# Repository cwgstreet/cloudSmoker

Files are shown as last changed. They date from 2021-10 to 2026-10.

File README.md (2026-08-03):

<div align="right">
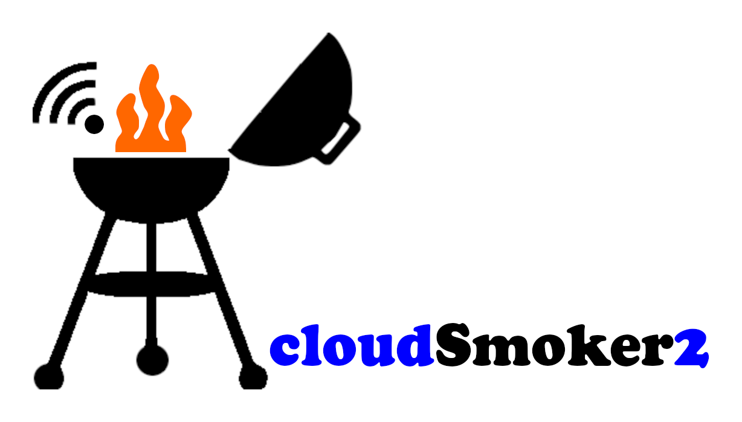
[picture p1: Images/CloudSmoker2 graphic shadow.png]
CloudSmoker2 Graphic
  
</div>
<br>

---

#  cloudSmoker2

# :construction: **Under Development**

⚠️ **Version 2 Notice:** 
<br>

**This is the active development 
branch for cloudSmoker V2. The original design is now deprecated but remains available on the v1-legacy branch.**

___





# Project Summary

The **cloudSmoker** is a WiFi-enabled barbeque temperature monitor designed to take the guesswork out of low-and-slow cooks. 

Building on the reliable foundation of the original cloudSmoker1 2022 release, Version 2 modernises the platform with a focus on precision, expanded capabilities, and a more comprehensive hardware design.

### What’s New in cloudSmoker2
*   **Expanded Monitoring:** Now supports up to four temperature probes for lager cooks.
*   **Enhanced Precision:** Improved measurement accuracy and response via higher-resolution ADC, optimised bias resistor selection plus improved filtering and ADC management.
*   **Modern Hardware:** Upgraded to a contemporary microcontroller, a refreshed display, and a custom 3D-printed enclosure.
*   **Professional Build:** Transitioning to a custom-manufactured PCB using contemporary SMD (Surface Mount) components for increased reliability and a more compact footprint.
*   **Refined Software:** Features seamless OTA (Over-The-Air) firmware updates, streamlined configuration menus, and robust exception monitoring.

### How it Works
The device tracks critical data points, such as pit and internal meat temperatures, and syncs them to an IoT dashboard. This allows for remote monitoring of real-time graphs and gauges from any browser or smartphone. 

To ensure the cook stays on track, the system sends push notifications if temperatures drift or once the meat reaches its target. The project is designed to be cooker-agnostic, making it a reliable companion for a variety of smokers and BBQ setups.

> ### 🌟 **Update:** cloudSmoker2 development is progressing!
>
1) **Boards now built and firmware port / enhancement is underway.**

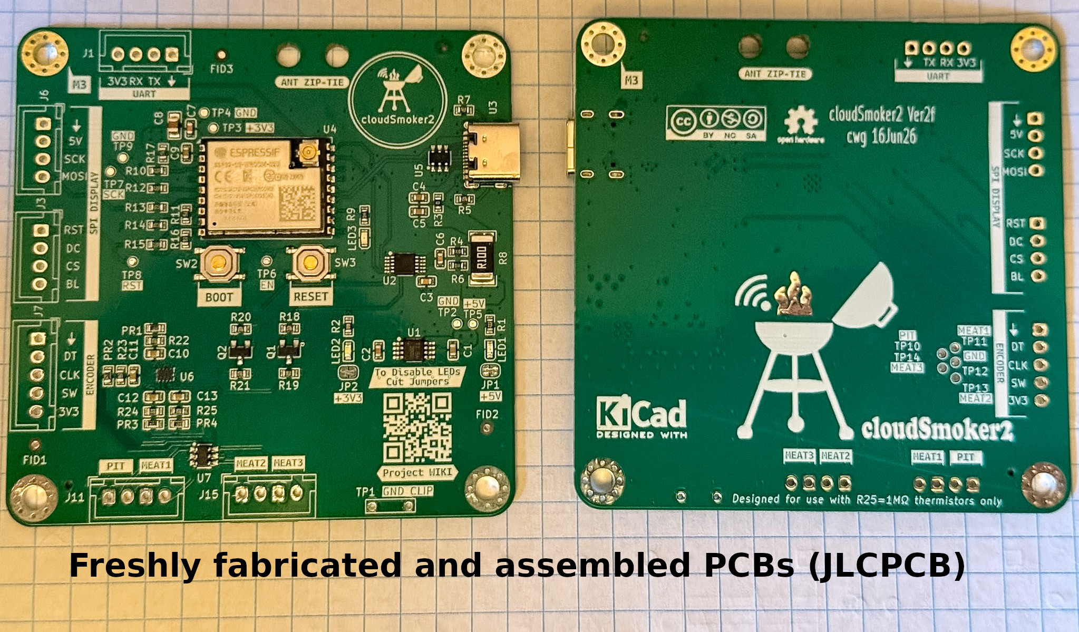
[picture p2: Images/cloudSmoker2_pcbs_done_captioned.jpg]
 

<br clear="left"/>
<br>

2) **3D printed enclosure design well advanced**
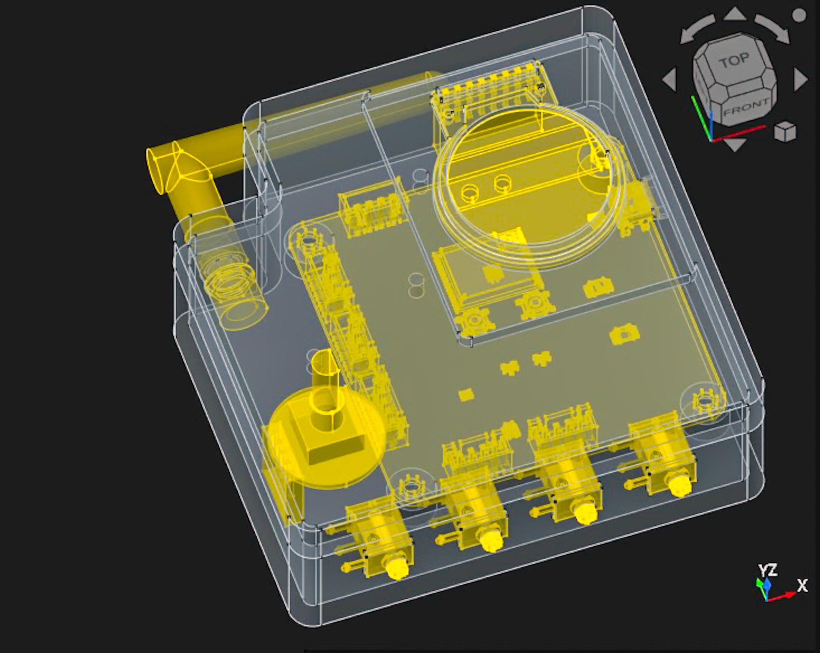
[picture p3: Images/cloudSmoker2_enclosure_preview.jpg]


<br clear="left"/>
<br>

<br>
<br>
<br>
<br>

---

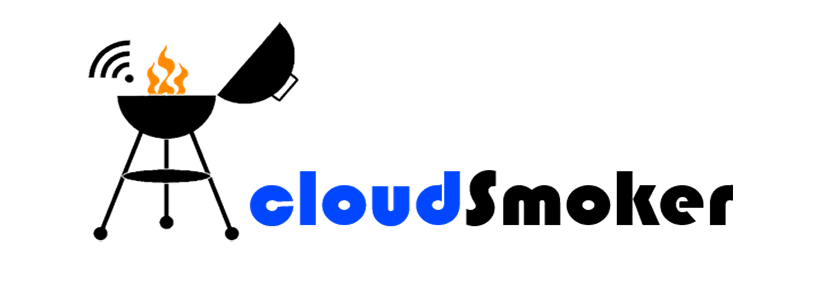
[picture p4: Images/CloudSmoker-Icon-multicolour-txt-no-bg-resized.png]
 
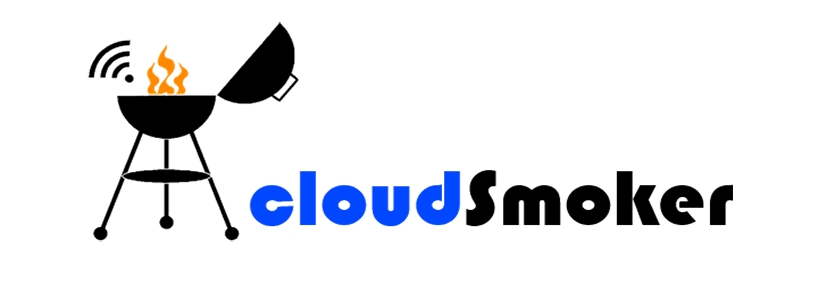
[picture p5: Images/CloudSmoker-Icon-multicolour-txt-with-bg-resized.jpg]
  

<br>

<br>

# cloudSmoker (v1-legacy) #

## 📜 Legacy Support (Version 1.0)
The original version of this project was based on an **ESP8266** and was built on **Veroboard**. While it is no longer the main focus of development, you can still access all the original files:

*   **[Version 1.0 Release Page](https://github.com/cwgstreet/cloudSmoker/releases/tag/v1.0)**
    *   `Hardware_v1.0.zip`: Includes Fritzing layouts, PDF schematics, and build photos.
    *   `Firmware_v1.0.zip`: The stable code and compiled `.bin` for the original build.

<!-- >**Note:** If you are building this project for the first time, we recommend using the **Version 2** PCB files found in this main branch. -->

**WiFi BBQ Temperature Monitor Project**

[comment]: <> (This project exists as a hands-on opportunity to learn more about electronics, IoT, Arduino / ESP8266 programming, GitHub markdown, etc)


<a href="https://thingspeak.com/channels/1679986">
    </a> 

 

<br>

<p align="center">
  <a href="https://hackaday.com/2022/08/09/smoking-meat-finds-natural-home-in-the-cloud/">
    
  </a>
</p>

### Updates (ver1)
1. **Removed pitTemp probe plug-in checks** - no longer displays LCD error or transmits pitTemp values to ThingSpeak if pit temperature probe is unplugged; necessary to allow pitTemp probe to be unplugged after meat is taken off grill so that resting meat temps can continue to be monitored (common to rest briskett in faux cambo for ~1 hour after removing meat from grill).
<br>
<br>

## Project Summary

The cloudSmoker Barbecue Monitor project is a WiFi-enable temperature monitor.  cloudSmoker is designed to read two temperatures (pit and internal meat temperatures) within my Weber BBQ smoker and upload these to an IOT dashboard, allowing remote cloud monitoring of the cook progress showing temperature vs time graphs, gauges, etc, user-definable cooking notification setpoints and exception push notifications to my smartphone, say if the pit temperatures go outside of acceptable ranges and when the meat is done and ready to be removed.

The overall process flow is conceptualised as follows:

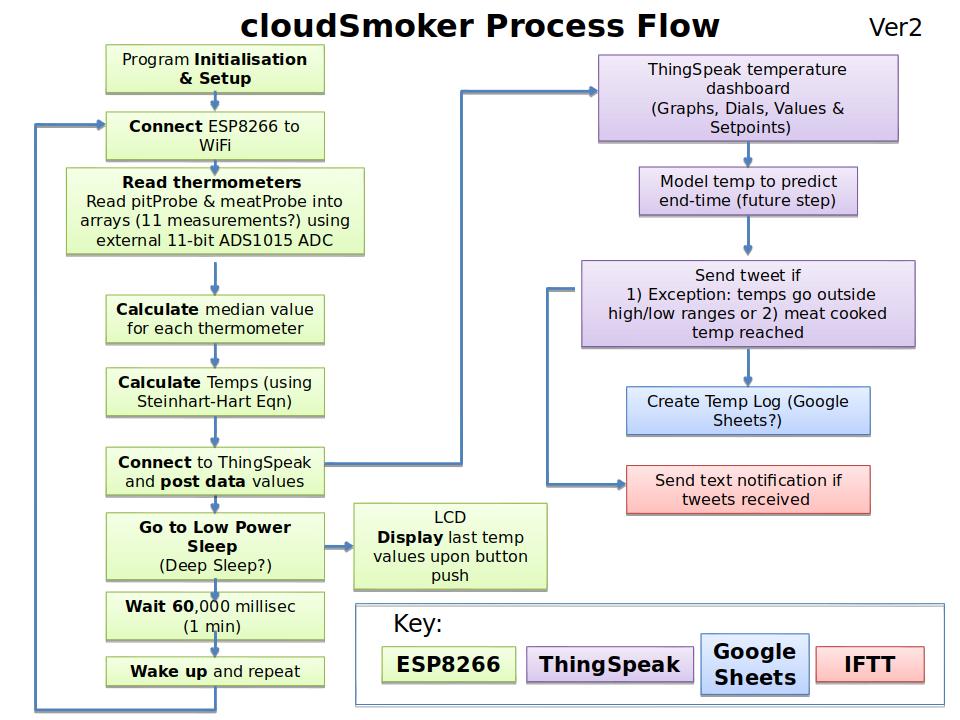
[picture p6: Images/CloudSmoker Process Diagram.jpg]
 

Hardware is based around the NodeMCU (V1.0) ESP8266-12E microcontroller module (for both for WiFi access and microcontroller), two Maverick ET-732/733 thermistor probes, an external ADS1015 "12-bit" ADC, plus a 1602 LCD and rotary encoder for user set-up configuration and display.  Minor thermistor and power filtering was also employed for stability.  

Coding was done using VS Code / PlatformIO IDE platform with data uploaded to ThingSpeak for display and further processing.   Push exception notifications are done through Twitter using Thingspeak's React / ThingTweet functionality.  (:warning: Todo:  export cook logs to Google Sheets).

### Project Overview  ###

An extensive project overview and design process description can be found in the project [Wiki](https://github.com/cwgstreet/cloudSmoker/wiki) covering design goals, hardware, software, etc.  

### Hardware ###

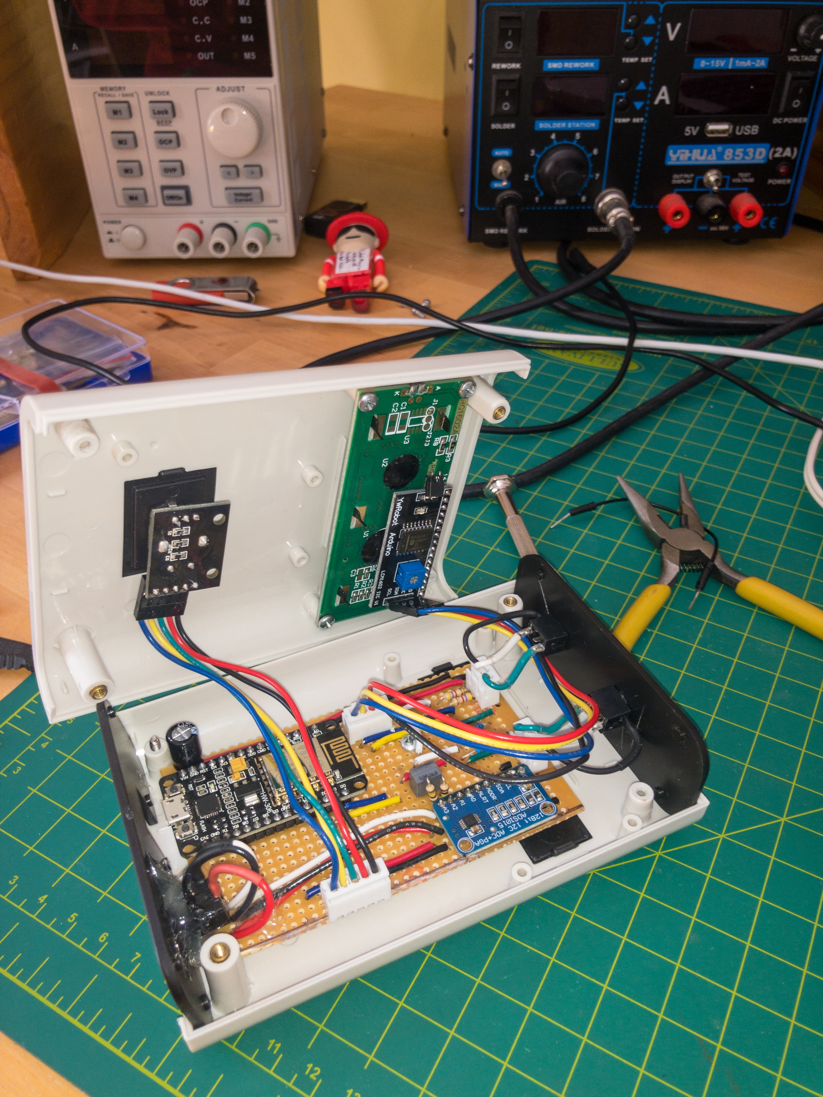
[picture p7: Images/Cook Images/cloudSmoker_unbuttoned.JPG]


The Hardware folder contains KiCad schematic, PCB board layouts (:warning: TODO) and selected datasheets (including the datasheet for the Semitec 105GT-2 Thermistor, that Maverick customer support kindly provided me.   👏 👍

Note that I have not found this datasheet available anywhere on the web and many other projects incorrectly characterised the Maverick ET-732/733 probes as being based on a 10k ohm thermistor (when it's actually 1M ohm!).  This incorrect assumption frequebtly led to poor bias resistor selection, resulting in poor measurement acuracy.  As a result, these Maverick thermistors were often not highly regrded.  For example, one project concluded they were [acceptable, but not recommended thermistor choice](https://github.com/CapnBry/HeaterMeter/wiki/HeaterMeter-Probes).   

### cloudSmoker ###

This folder contains the full cloudSmoker software (sketch and libraries); developed under VSCode / Platformio IDE rather than Arduino IDE so folder structure reflect Platformio structure.  Note that the project code base is over 1600 lines total and makes extensive use of user and public libraries.

### Images ###

Self-explanatory

### Project Dashboard ###
A public ThingSpeak [cloudSmoker dashboard](https://thingspeak.com/channels/1679986) is available

<p align="center">
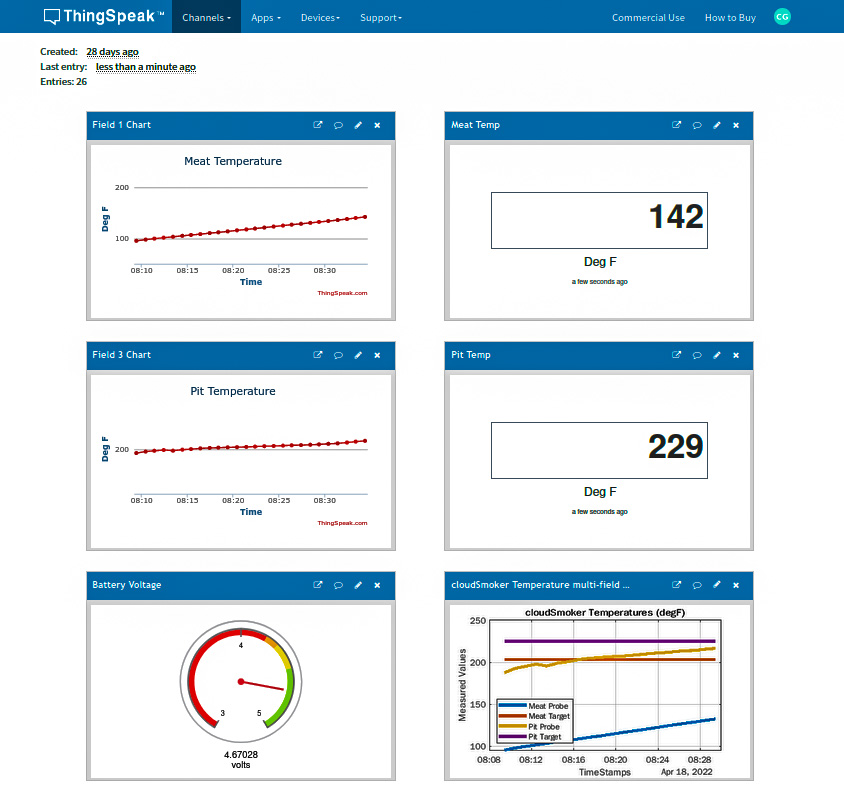
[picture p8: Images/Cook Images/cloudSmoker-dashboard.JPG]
  
</p>

### Licence ###

**cloudSmoker (ver1):** MIT Licence.  Note that licence terms have changed for cloudSmoker2 (Ver2)

--- END ---

<p align="center">
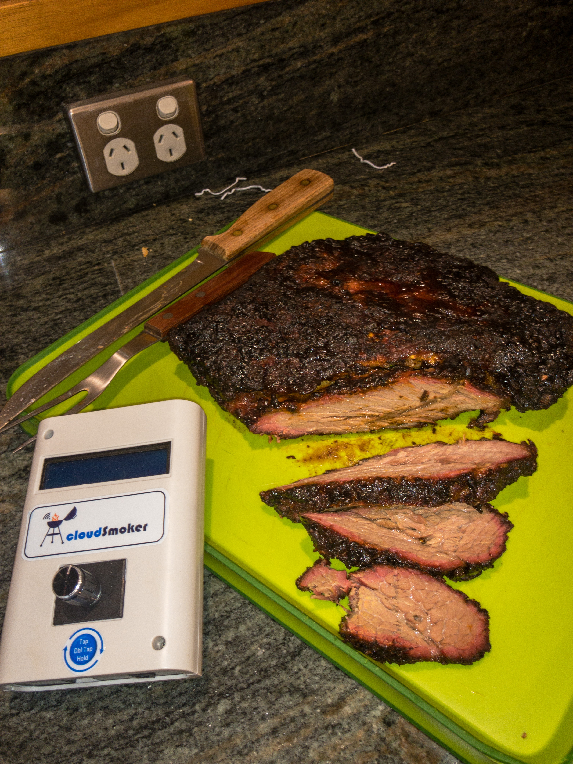
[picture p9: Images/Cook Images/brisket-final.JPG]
  
</p>

<br>
<br>

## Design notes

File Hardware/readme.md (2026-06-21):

# cloudSmoker2 Hardware Reference

This directory serves as the root hardware repository for the **cloudSmoker2** platform. It contains mechanical housing documents, sensor calibration resources, manufacturing documentation, and the complete electronic design suite.

---

## 📂 Repository Structure

```text
├── KiCad9/                          # Core ECAD design environment (KiCad 9.x)
│   ├── cloudSmoker_ver2f.kicad_pro  # Main project configuration
│   ├── cloudSmoker_ver2f.kicad_sch  # 4-Layer Schematic blueprints
│   ├── cloudSmoker_ver2f.kicad_pcb  # Mixed-signal PCB layout 
│   ├── sym-lib-table & fp-lib-table # Local dependency resolution tables
│   ├── JLCImport.pretty/            # Component footprints (.kicad_mod)
│   ├── JLCImport.3dshapes/          # 3D structural clearance models (.step / .wrl)
│   ├── production/                  # Manufacturing artifacts (Gerbers, BOM, CPL)
│   └── svg_files/                   # Dynamic high-resolution hardware dashboard graphics
│
├── Thermistor datasheet/            # High-temperature physical probe reference material
│   ├── ET-732 (Thermistor) datasheet scan.pdf
│   └── Maverick ET-732 - 733 (Semitec 105GT-2 Thermistor) datasheet.pdf
│
├── arduino_housing_01_160717_CAD.PDF.pdf   # Mechanical chassis reference dimensions (cloudSmoker1)
└── licence.md                               # Open-source hardware licensing framework
```

## ⚙️ Key File Subsystems

### 1. Electronic Design Automation (`KiCad9/`)
* **ECAD Engine**: Engineered exclusively inside **KiCad 9**. Backward-compatibility issues can occur if parsed with older software builds.
* **Component Portability**: Component symbols, tracking pads, and 3D packages are completely containerized locally inside the `JLCImport` folders. External global library paths are not required to audit the board.
* **Fabrication Files**: The `KiCad9/production/` subdirectory houses pre-compiled fabrication packages including the zipped Gerber layer arrays, coordinates tables (`positions.csv`), and structural parts listings (`bom.csv`).

### 2. Thermistor Data
* **`Thermistor datasheet/`**: Houses structural lookup sheets for the Semitec 105GT-2 high-temp food probes.

### 3. Physical & Enclosure Overlays
* **`arduino_housing_01_160717_CAD.PDF.pdf`**: Legacy cloudSmoker1 mechanical profile drawing used to verify PCB perimeter cuts, mounting hole positions, and connector face alignments against existing chassis designs.

---

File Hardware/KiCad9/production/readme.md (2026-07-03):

**This directory was created with Kicad9 / Fabrication Toolkit plug-in.**

The fabrication toolkit extracts the files necessary for (JLCPCB)[https://jlcpcb.com/] PCB fabrication and PCBA assembly:
 1) cloudSmoker_ver2_2f.zip -> gerber files
 2) bom.csv -> Bill of Materials including JLCPCB Part Numbers
 3) positions.csv -> component positions file for pick & place

Note:  When ordering, check fab house component positions and orientations carefully as translation errors occur between Kicad9 and JLCPCB despite using JLCPCB / EasyEDA footprints imported with JLC Import plug-in

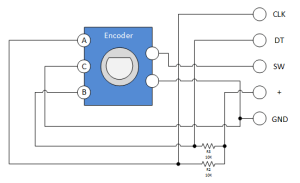
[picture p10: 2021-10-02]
Images/Keyes-KY-040-Rotary-Encoder-Module-Schematic.png

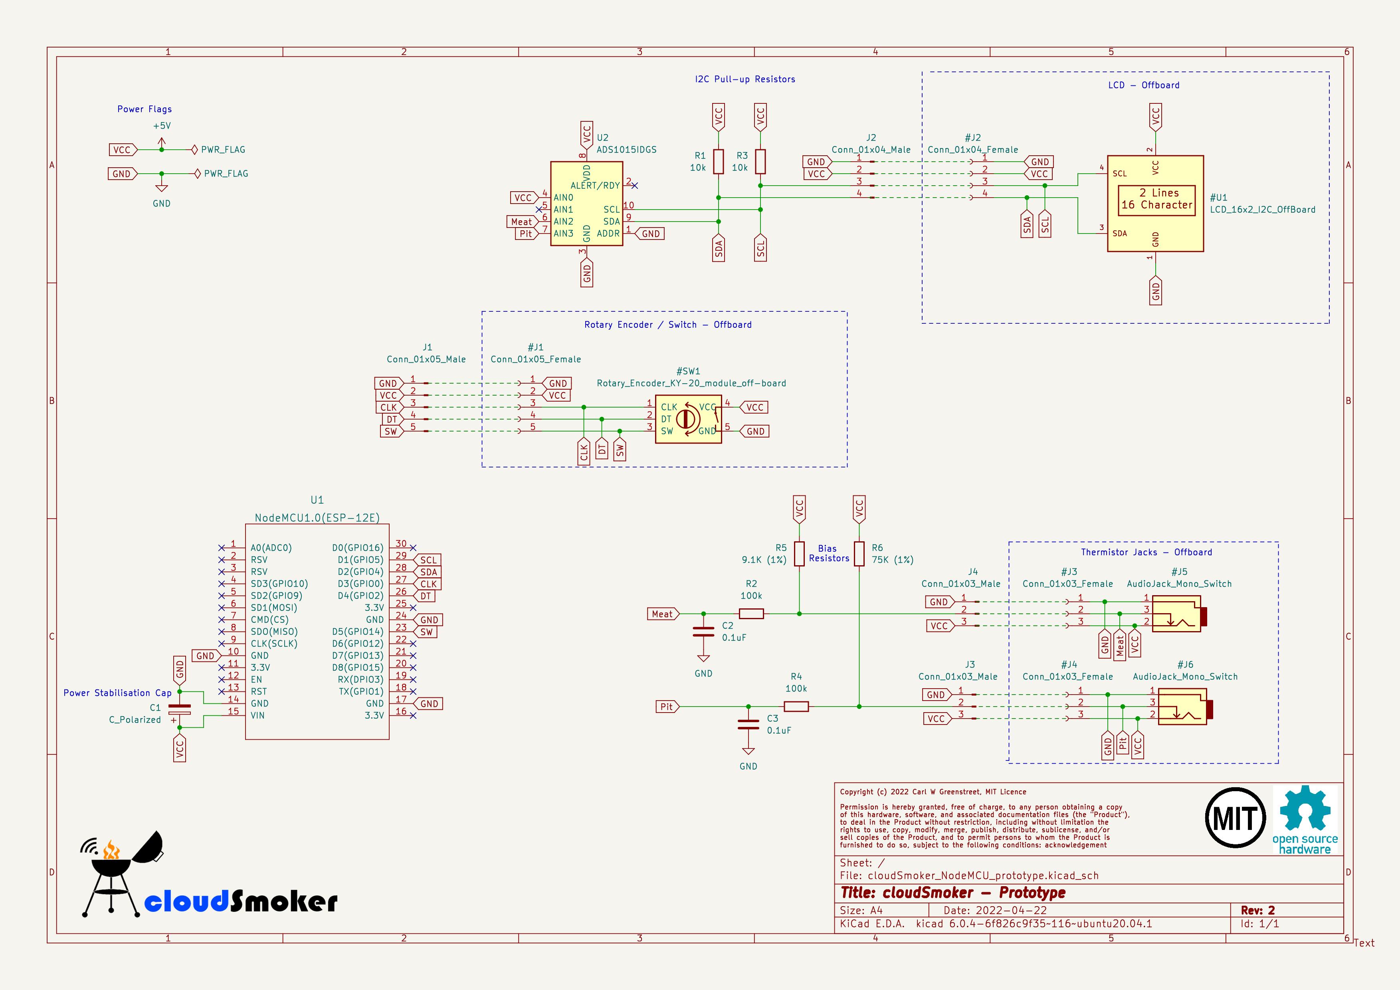
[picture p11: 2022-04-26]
Images/cloudSmoker_prototype_schematic_kicad6.jpg

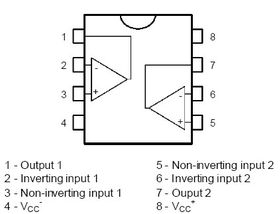
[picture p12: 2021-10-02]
Images/lm358_opamp_pinout.jpg

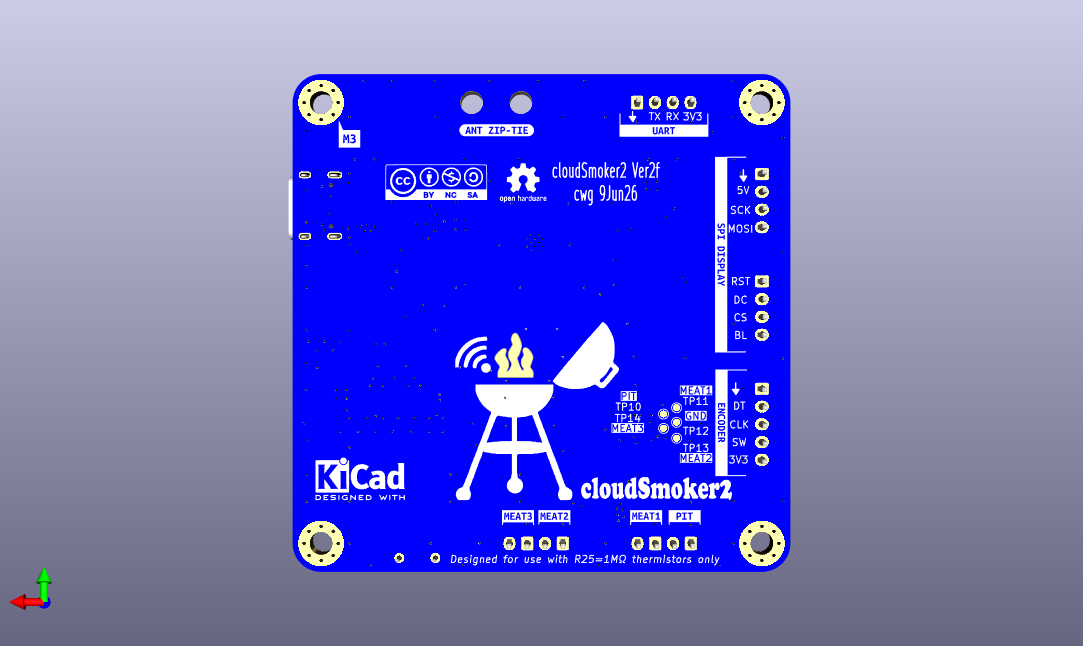
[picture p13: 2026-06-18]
Hardware/KiCad9/svg_files/view3_bottom.png

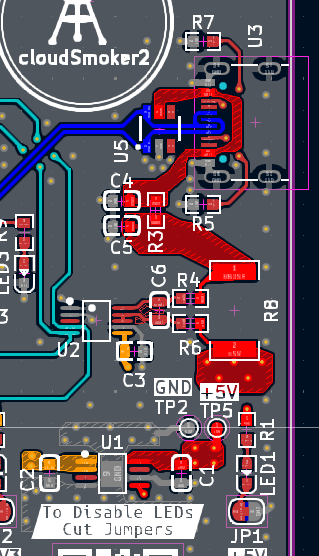
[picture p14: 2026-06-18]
Hardware/KiCad9/svg_files/power_section_closeup.png

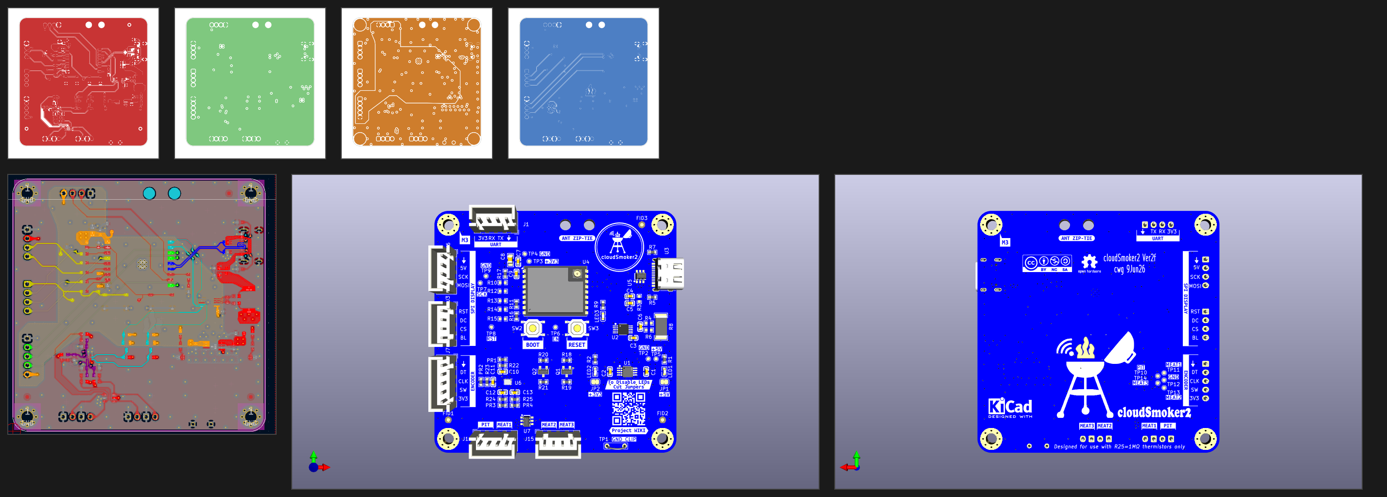
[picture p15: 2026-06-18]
Hardware/KiCad9/svg_files/pcb_dashboard.png

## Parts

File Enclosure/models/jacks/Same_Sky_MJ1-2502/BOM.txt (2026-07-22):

3DX_Same_Sky_Supplier: Same Sky
3DX_Same_Sky_Description: 2.5 mm, Mono, Right Angle, Through Hole, Threaded Bushing, 2 Conductors, 1 Internal Switch, Audio Jack Connector
3DX_Same_Sky_Model Number: MJ1-2502

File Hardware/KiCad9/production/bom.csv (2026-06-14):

Designator | Footprint | Quantity | Value | LCSC Part #
C1, C10, C11, C12, C13, C9 | CL10A105KB8NNNC | 6 | 1uF | C15849
C2 | CL10A225KO8NNNC | 1 | 2.2uF | C23630
C3, C6, C7 | CC0603KRX7R9BB104 | 3 | 100nF | C14663
C4, C5 | CC0603KRX7R9BB104 | 2 | 470nF | C1623
C8 | CL21A106KAYNNNE | 1 | 10uF | C15850
LED1 | KT-0603R | 1 | Red | C2286
LED2 | 0603White_light_C2290 | 1 | White | C2290
LED3 | FC-1608YXK-585F08 | 1 | Yellow | C89811
PR1, PR2, PR3, PR4 | PTFR0603B120KP9 | 4 | 120k 0.1%TF | C351687
Q1, Q2 | BSS138_C7420339 | 2 | BSS138 | C7420339
R1 | 0603WAF2201T5E | 1 | 2.2k | C4190
R10, R12, R13, R14, R15 | R0603_part-C23345 | 5 | 22 | C23345
R11, R16, R17, R19, R21, R22, R23, R24, R25 | 0603WAF1002T5E | 9 | 10k | C25804
R18, R20, R5, R7 | 0603WAF5101T5E | 4 | 5.1k | C23186
R2 | 0603WAF1001T5E | 1 | 1k | C21190
R3 | R0603_part-C21189_0-ohm | 1 | 0 ohm | C21189
R4, R6 | R0603_part-C22859_10-ohm | 2 | 10 | C22859
R8 | RLP25FEER100 | 1 | 100 mOhm Shunt | C160587
R9 | 0603WAF1000T5E | 1 | 100 | C22775
SW2, SW3 | TS-1187A-B-A-B | 2 | SW_Push_Dual | C318884
U1 | TLV76733DGNR | 1 | TLV76733DGNR | C2873382
U2 | INA226AIDGSR | 1 | INA226AIDGSR | C49851
U3 | USB_C_Receptacle_G-Switch_GT-USB-7010ASV clipped | 1 | GT-USB-7010ASV | C2988369
U4 | ESP32-C3-WROOM-02U | 1 | ESP32-C3-WROOM-02U-N4 | C2926676
U5, U7 | SRV05-4-P-T7 | 2 | SRV05-4-P-T7 | C85364
U6 | ADS1115IRUGR | 1 | ADS1115IRUGR | C2651328

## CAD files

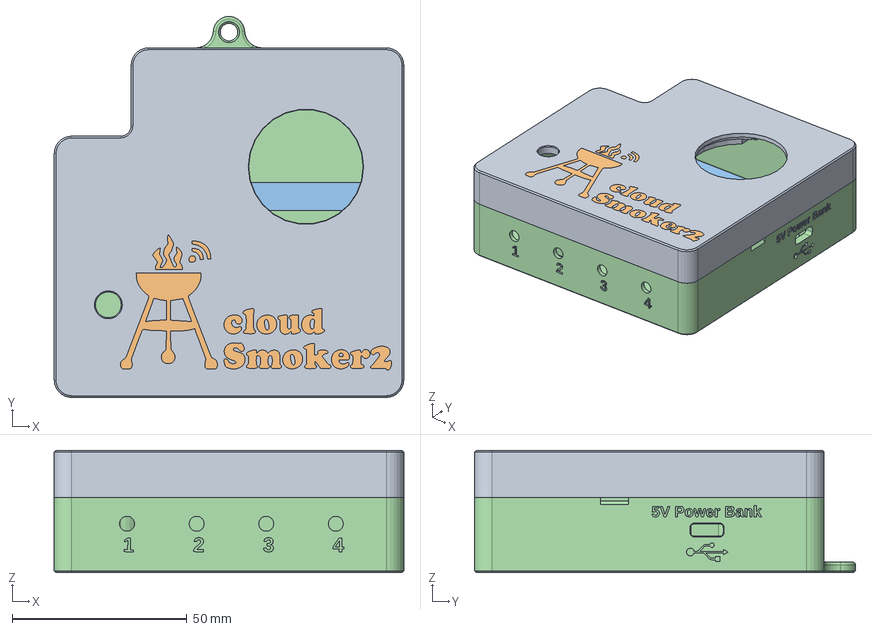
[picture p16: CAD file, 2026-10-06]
Enclosure/cloudSmoker2_enclosure_ver2b.FCStd
100.0 x 109.0 x 35.0 mm
top_enclosure_refined_copy
top_logo_refined_copy
display_clip_refined_copy
base_enclosure_refined_copy

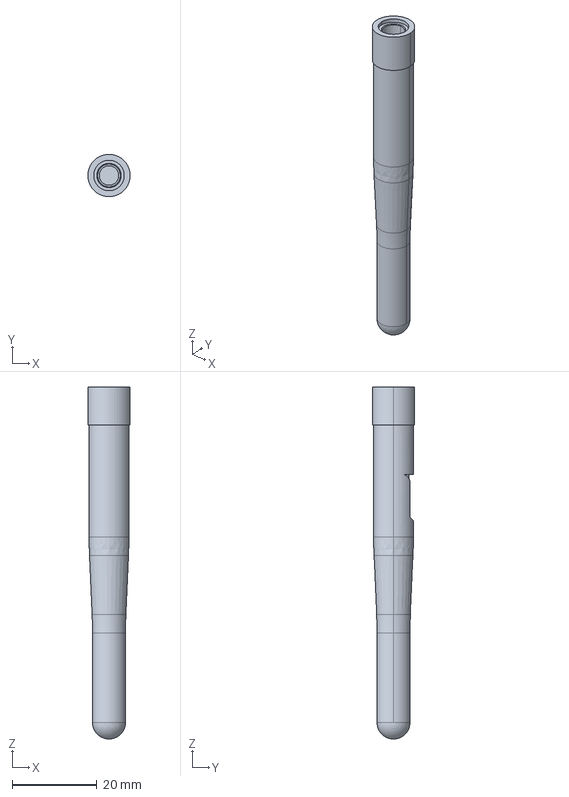
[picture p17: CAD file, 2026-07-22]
Enclosure/models/antenna/ENG_CVM_CVM_L9000081-01_A.3d_stp/c-l9000081-01-a-3d.stp
10.0 x 10.0 x 83.1 mm

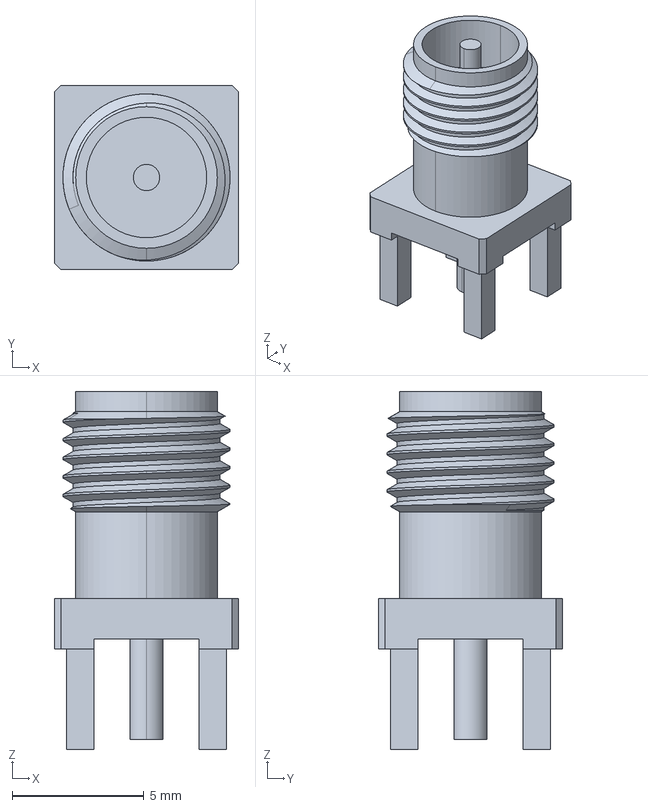
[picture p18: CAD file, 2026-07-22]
Enclosure/models/antenna/RP-SMA_conn/c-conrevsma001-g-c-3d.stp
7.00 x 7.00 x 13.6 mm

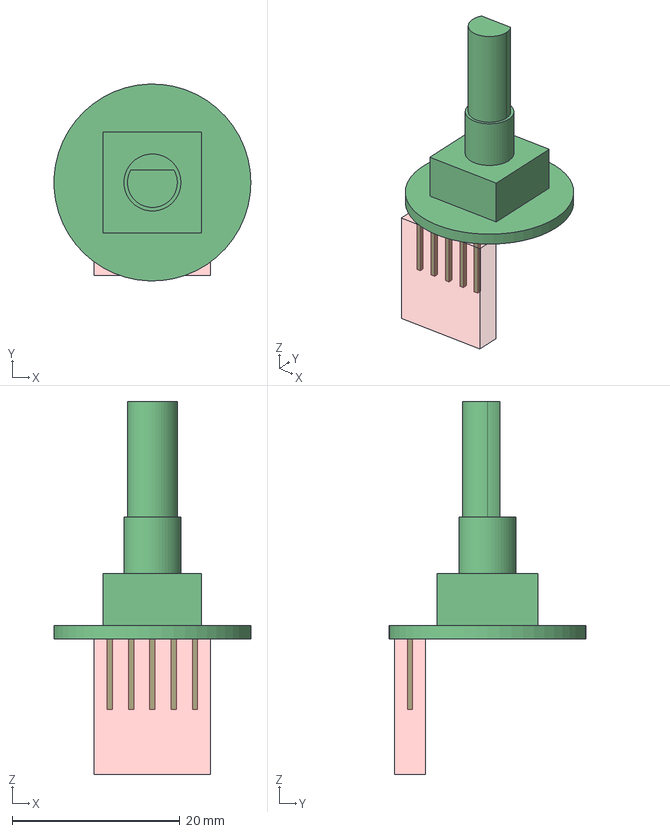
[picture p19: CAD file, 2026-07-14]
Enclosure/models/EC11 rotary encoder/EC11_encoder_module.step
23.5 x 23.5 x 44.5 mm
Encoder_DuPont_Clearance
EC11_Round_Module

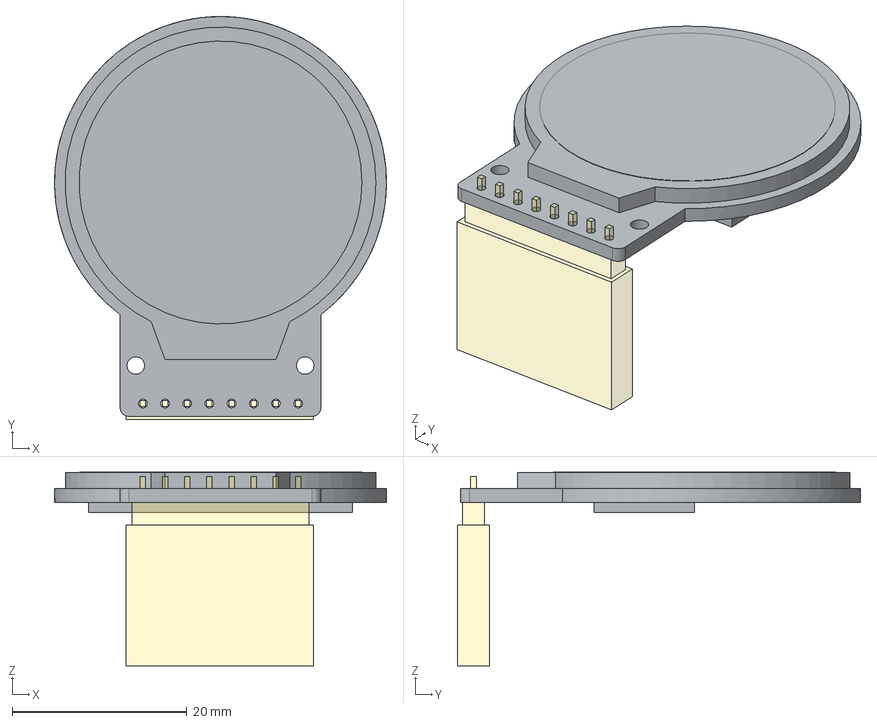
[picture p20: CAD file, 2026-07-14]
Enclosure/models/GC9A01_display/GC9A01_Dsiplay.step
38.0 x 46.2 x 22.2 mm
Male_Header_1x08 Binder
DuPont_1x8_Clearance_Zone Binder

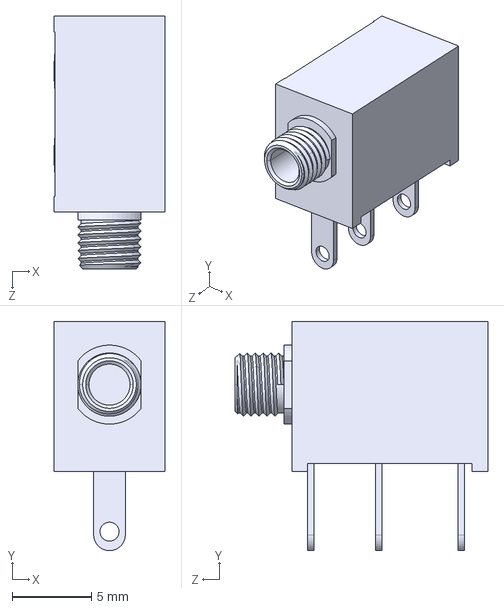
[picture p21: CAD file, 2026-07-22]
Enclosure/models/jacks/Same_Sky_MJ1-2502/Same_Sky_MJ1-2502.step
7.00 x 14.5 x 16.0 mm

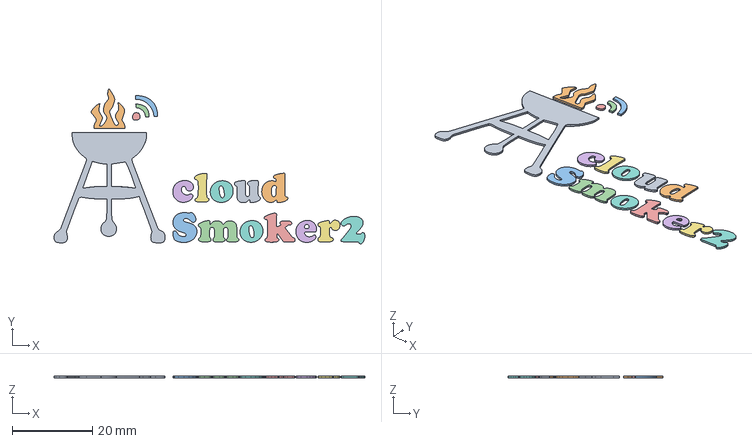
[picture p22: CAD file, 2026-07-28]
Enclosure/models/logo/cloudSmoker_logo.step
77.6 x 38.6 x 0.4 mm

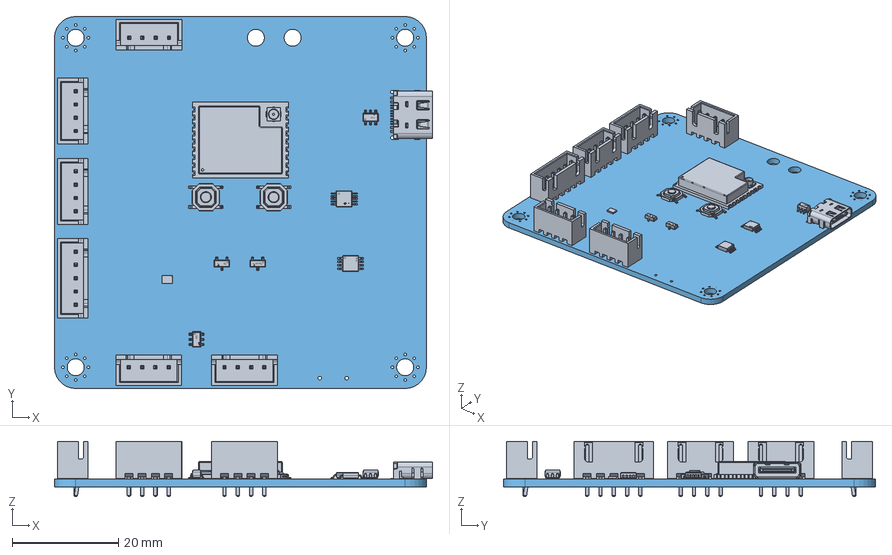
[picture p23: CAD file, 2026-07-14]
Enclosure/models/pcb/cloudSmoker_ver2f.step
71.2 x 70.0 x 10.4 mm
INA226AIDGSR
JST_XH_B4B-XH-A_1x04_P2.50mm_Vertical x 5
TLV76733DGNR
ADS1115IRUGR
BSS138_C7420339 x 2
SRV05-4-P-T7 x 2
ESP32-C3-WROOM-02U
TS-1187A-B-A-B x 2
GT-USB-7010ASV x 3
JST_XH_B5B-XH-A_1x05_P2.50mm_Vertical
cloudSmoker_ver2f_PCB

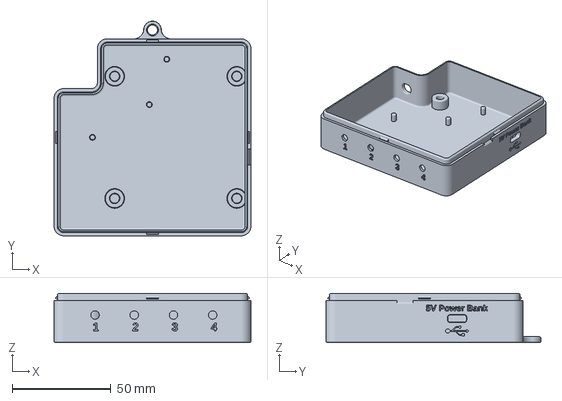
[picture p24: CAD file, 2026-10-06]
Enclosure/print_files/cloudSmoker2_ver2b_base_enclosure_v1.3mf
100.0 x 109.0 x 25.0 mm

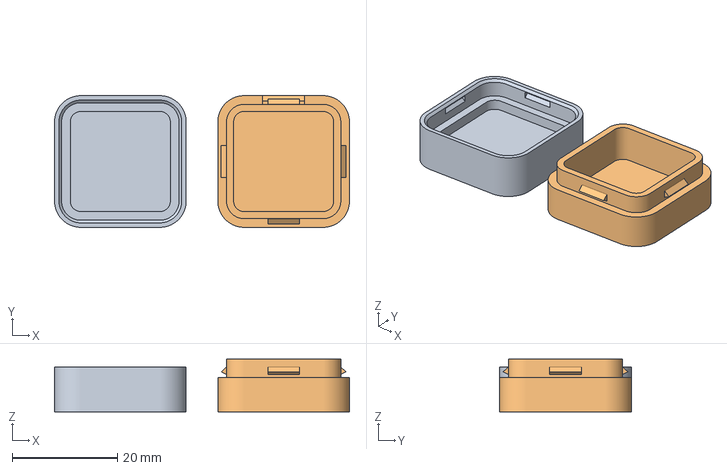
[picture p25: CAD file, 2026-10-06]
Enclosure/print_files/snap-fit_test/snap_fit_test-top-bottom.3mf
56.0 x 25.0 x 10.0 mm
snap_fit_test-top
snap_fit_test-Base

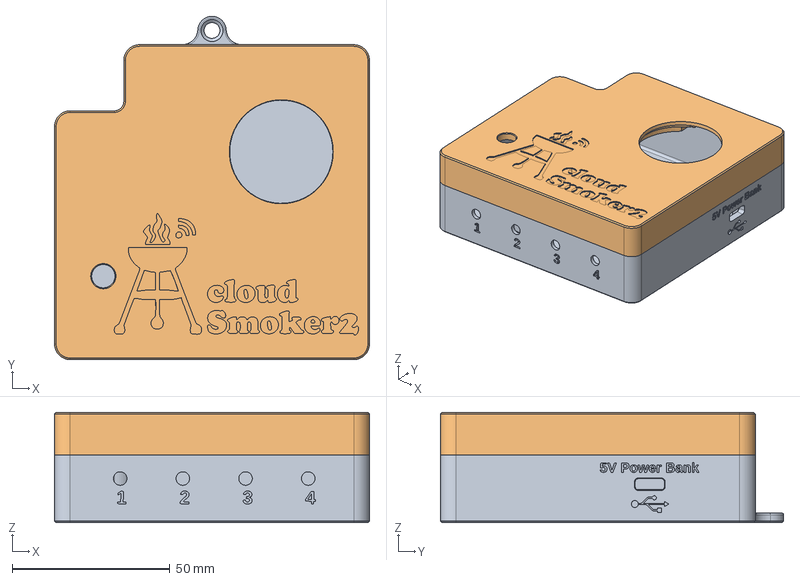
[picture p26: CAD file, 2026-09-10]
Enclosure/cloudSmoker2_enclosure_ver2a.FCStd
100.0 x 109.0 x 35.0 mm
base_enclosure
top_enclosure

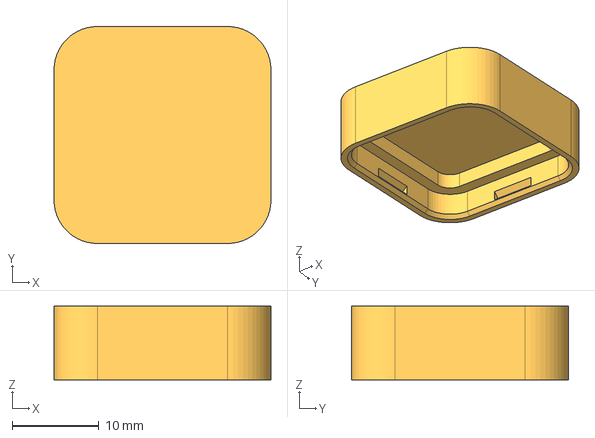
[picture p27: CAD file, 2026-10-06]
Enclosure/print_files/snap-fit_test/snap_fit_test-top.step
25.0 x 25.0 x 8.50 mm

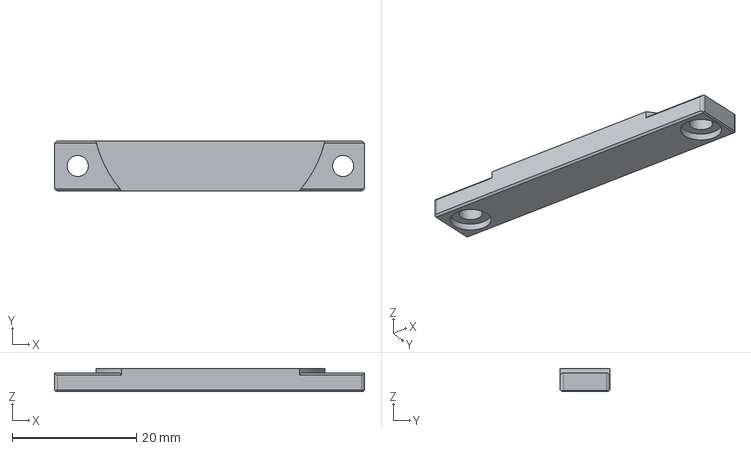
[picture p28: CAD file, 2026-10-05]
Enclosure/print_files/cloudSmoker2_ver2b_top_enclosure_display_clip.step
50.0 x 8.00 x 3.75 mm

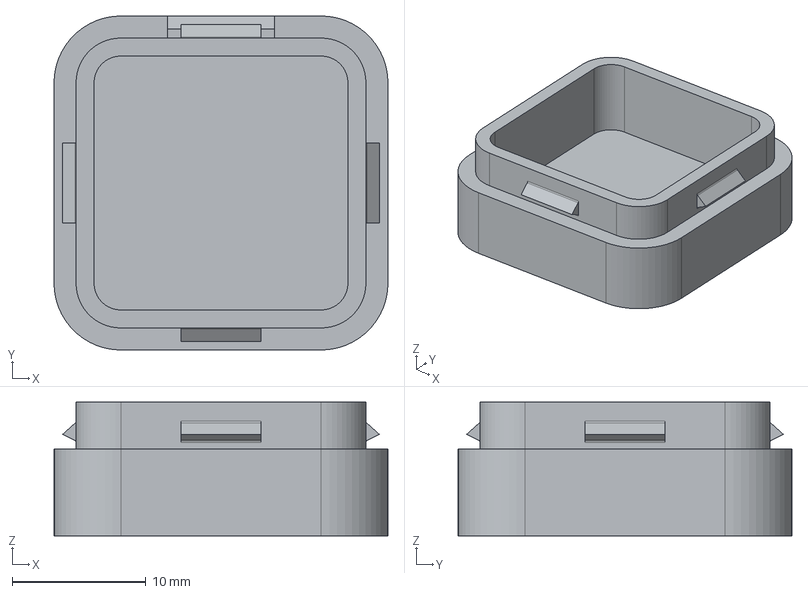
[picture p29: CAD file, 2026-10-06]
Enclosure/print_files/snap-fit_test/snap_fit_test-Base.step
25.0 x 25.0 x 10.0 mm

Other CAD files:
Hardware/KiCad9/cloudSmoker_ver2f.step
Enclosure/print_files/cloudSmoker2_ver2b_base_enclosure.step
Enclosure/print_files/cloudSmoker2_ver2b_top_enclosure.step
Enclosure/print_files/cloudSmoker2_ver2b_top_enclosure_logo.step
Enclosure/models/logo/cloudSmoker_logo.FCStd
Enclosure/print_files/cloudSmoker2_ver2a_top_enclosure.step
Enclosure/print_files/cloudSmoker2_ver2a_top_enclosure_display_clip.step
Enclosure/print_files/cloudSmoker2_ver2a_top_enclosure_logo.step

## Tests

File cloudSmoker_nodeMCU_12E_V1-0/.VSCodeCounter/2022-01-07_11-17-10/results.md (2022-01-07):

# Summary

Date : 2022-01-07 11:17:10

Directory /Users/carlwgreenstreet/Documents/PlatformIO/Projects/cloudSmoker/cloudSmoker_nodeMCU_12E_V1-0

Total : 14 files,  673 codes, 354 comments, 192 blanks, all 1219 lines

[details](details.md)

## Languages
| language | files | code | comment | blank | total |
| :--- | ---: | ---: | ---: | ---: | ---: |
| C++ | 13 | 662 | 341 | 189 | 1,192 |
| Ini | 1 | 11 | 13 | 3 | 27 |

## Directories
| path | files | code | comment | blank | total |
| :--- | ---: | ---: | ---: | ---: | ---: |
| . | 14 | 673 | 354 | 192 | 1,219 |
| lib | 12 | 608 | 247 | 164 | 1,019 |
| lib/helper_functions | 2 | 24 | 24 | 12 | 60 |
| lib/lcd | 2 | 273 | 65 | 52 | 390 |
| lib/periphials | 2 | 30 | 33 | 14 | 77 |
| lib/press_type | 2 | 92 | 44 | 29 | 165 |
| lib/smokerStates | 2 | 93 | 48 | 32 | 173 |
| lib/wrapEncoder | 2 | 96 | 33 | 25 | 154 |
| src | 1 | 54 | 94 | 25 | 173 |

[details](details.md)

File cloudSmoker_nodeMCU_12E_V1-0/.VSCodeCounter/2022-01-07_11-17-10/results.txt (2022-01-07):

Date : 2022-01-07 11:17:10
Directory : /Users/carlwgreenstreet/Documents/PlatformIO/Projects/cloudSmoker/cloudSmoker_nodeMCU_12E_V1-0
Total : 14 files,  673 codes, 354 comments, 192 blanks, all 1219 lines

Languages
+----------+------------+------------+------------+------------+------------+
| language | files      | code       | comment    | blank      | total      |
+----------+------------+------------+------------+------------+------------+
| C++      |         13 |        662 |        341 |        189 |      1,192 |
| Ini      |          1 |         11 |         13 |          3 |         27 |
+----------+------------+------------+------------+------------+------------+

Directories
+------------------------------------------------------------------------------------------------------------------------------------------+------------+------------+------------+------------+------------+
| path                                                                                                                                     | files      | code       | comment    | blank      | total      |
+------------------------------------------------------------------------------------------------------------------------------------------+------------+------------+------------+------------+------------+
| .                                                                                                                                        |         14 |        673 |        354 |        192 |      1,219 |
| lib                                                                                                                                      |         12 |        608 |        247 |        164 |      1,019 |
| lib/helper_functions                                                                                                                     |          2 |         24 |         24 |         12 |         60 |
| lib/lcd                                                                                                                                  |          2 |        273 |         65 |         52 |        390 |
| lib/periphials                                                                                                                           |          2 |         30 |         33 |         14 |         77 |
| lib/press_type                                                                                                                           |          2 |         92 |         44 |         29 |        165 |
| lib/smokerStates                                                                                                                         |          2 |         93 |         48 |         32 |        173 |
| lib/wrapEncoder                                                                                                                          |          2 |         96 |         33 |         25 |        154 |
| src                                                                                                                                      |          1 |         54 |         94 |         25 |        173 |
+------------------------------------------------------------------------------------------------------------------------------------------+------------+------------+------------+------------+------------+

Files
+------------------------------------------------------------------------------------------------------------------------------------------+----------+------------+------------+------------+------------+
| filename                                                                                                                                 | language | code       | comment    | blank      | total      |
+------------------------------------------------------------------------------------------------------------------------------------------+----------+------------+------------+------------+------------+
| /Users/carlwgreenstreet/Documents/PlatformIO/Projects/cloudSmoker/cloudSmoker_nodeMCU_12E_V1-0/lib/helper_functions/helper_functions.cpp | C++      |         10 |         14 |          6 |         30 |
| /Users/carlwgreenstreet/Documents/PlatformIO/Projects/cloudSmoker/cloudSmoker_nodeMCU_12E_V1-0/lib/helper_functions/helper_functions.h   | C++      |         14 |         10 |          6 |         30 |
| /Users/carlwgreenstreet/Documents/PlatformIO/Projects/cloudSmoker/cloudSmoker_nodeMCU_12E_V1-0/lib/lcd/lcd.cpp                           | C++      |        237 |         40 |         37 |        314 |
| /Users/carlwgreenstreet/Documents/PlatformIO/Projects/cloudSmoker/cloudSmoker_nodeMCU_12E_V1-0/lib/lcd/lcd.h                             | C++      |         36 |         25 |         15 |         76 |
| /Users/carlwgreenstreet/Documents/PlatformIO/Projects/cloudSmoker/cloudSmoker_nodeMCU_12E_V1-0/lib/periphials/periphials.cpp             | C++      |         12 |         17 |          5 |         34 |
| /Users/carlwgreenstreet/Documents/PlatformIO/Projects/cloudSmoker/cloudSmoker_nodeMCU_12E_V1-0/lib/periphials/periphials.h               | C++      |         18 |         16 |          9 |         43 |
| /Users/carlwgreenstreet/Documents/PlatformIO/Projects/cloudSmoker/cloudSmoker_nodeMCU_12E_V1-0/lib/press_type/press_type.cpp             | C++      |         64 |         21 |         16 |        101 |
| /Users/carlwgreenstreet/Documents/PlatformIO/Projects/cloudSmoker/cloudSmoker_nodeMCU_12E_V1-0/lib/press_type/press_type.h               | C++      |         28 |         23 |         13 |         64 |
| /Users/carlwgreenstreet/Documents/PlatformIO/Projects/cloudSmoker/cloudSmoker_nodeMCU_12E_V1-0/lib/smokerStates/smokerStates.cpp         | C++      |         71 |         33 |         24 |        128 |
| /Users/carlwgreenstreet/Documents/PlatformIO/Projects/cloudSmoker/cloudSmoker_nodeMCU_12E_V1-0/lib/smokerStates/smokerStates.h           | C++      |         22 |         15 |          8 |         45 |
| /Users/carlwgreenstreet/Documents/PlatformIO/Projects/cloudSmoker/cloudSmoker_nodeMCU_12E_V1-0/lib/wrapEncoder/wrapEncoder.cpp           | C++      |         64 |         12 |         13 |         89 |
| /Users/carlwgreenstreet/Documents/PlatformIO/Projects/cloudSmoker/cloudSmoker_nodeMCU_12E_V1-0/lib/wrapEncoder/wrapEncoder.h             | C++      |         32 |         21 |         12 |         65 |
| /Users/carlwgreenstreet/Documents/PlatformIO/Projects/cloudSmoker/cloudSmoker_nodeMCU_12E_V1-0/platformio.ini                            | Ini      |         11 |         13 |          3 |         27 |
| /Users/carlwgreenstreet/Documents/PlatformIO/Projects/cloudSmoker/cloudSmoker_nodeMCU_12E_V1-0/src/cloudSmoker_nodeMCU_main.cpp          | C++      |         54 |         94 |         25 |        173 |
| Total                                                                                                                                    |          |        673 |        354 |        192 |      1,219 |
+------------------------------------------------------------------------------------------------------------------------------------------+----------+------------+------------+------------+------------+

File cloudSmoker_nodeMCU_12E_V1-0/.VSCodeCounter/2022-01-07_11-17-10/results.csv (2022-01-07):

filename | "language" | "C++" | "Ini" | "comment" | "blank" | "total"
/Users/carlwgreenstreet/Documents/PlatformIO/Projects/cloudSmoker/cloudSmoker_nodeMCU_12E_V1-0/lib/helper_functions/helper_functions.cpp | "C++" | 10 | 0 | 14 | 6 | 30
/Users/carlwgreenstreet/Documents/PlatformIO/Projects/cloudSmoker/cloudSmoker_nodeMCU_12E_V1-0/lib/helper_functions/helper_functions.h | "C++" | 14 | 0 | 10 | 6 | 30
/Users/carlwgreenstreet/Documents/PlatformIO/Projects/cloudSmoker/cloudSmoker_nodeMCU_12E_V1-0/lib/lcd/lcd.cpp | "C++" | 237 | 0 | 40 | 37 | 314
/Users/carlwgreenstreet/Documents/PlatformIO/Projects/cloudSmoker/cloudSmoker_nodeMCU_12E_V1-0/lib/lcd/lcd.h | "C++" | 36 | 0 | 25 | 15 | 76
/Users/carlwgreenstreet/Documents/PlatformIO/Projects/cloudSmoker/cloudSmoker_nodeMCU_12E_V1-0/lib/periphials/periphials.cpp | "C++" | 12 | 0 | 17 | 5 | 34
/Users/carlwgreenstreet/Documents/PlatformIO/Projects/cloudSmoker/cloudSmoker_nodeMCU_12E_V1-0/lib/periphials/periphials.h | "C++" | 18 | 0 | 16 | 9 | 43
/Users/carlwgreenstreet/Documents/PlatformIO/Projects/cloudSmoker/cloudSmoker_nodeMCU_12E_V1-0/lib/press_type/press_type.cpp | "C++" | 64 | 0 | 21 | 16 | 101
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

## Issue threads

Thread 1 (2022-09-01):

ESP32

palmtreefrb, 2022-09-01:
The esp32 being relatively inexpensive and more powerful. Have you considered it as an alternative?

cwgstreet, 2022-09-03:
I couldn’t see the point of using an esp32 for this project as the ESP8266 board I selected was cheaper and adequate for my needs.  If you want / need esp32 functionality (say Bluetooth) it should be fairly trivial to port the code across.

Closed 2022-09-03.

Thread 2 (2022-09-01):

PCB?

jlandgrave62, 2022-09-01:
Did you ever get around to getting a PCB fabricated?

cwgstreet, 2022-09-03:
Not yet; the veroboard version is working fine and I’m busy elsewhere.  I’ve drawn up the schematic in KiCad and the files are available on the cloudSmoker repository.  It won’t take long if you want to lay out your own board.

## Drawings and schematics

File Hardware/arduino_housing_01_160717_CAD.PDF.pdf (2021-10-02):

2.00

2.17

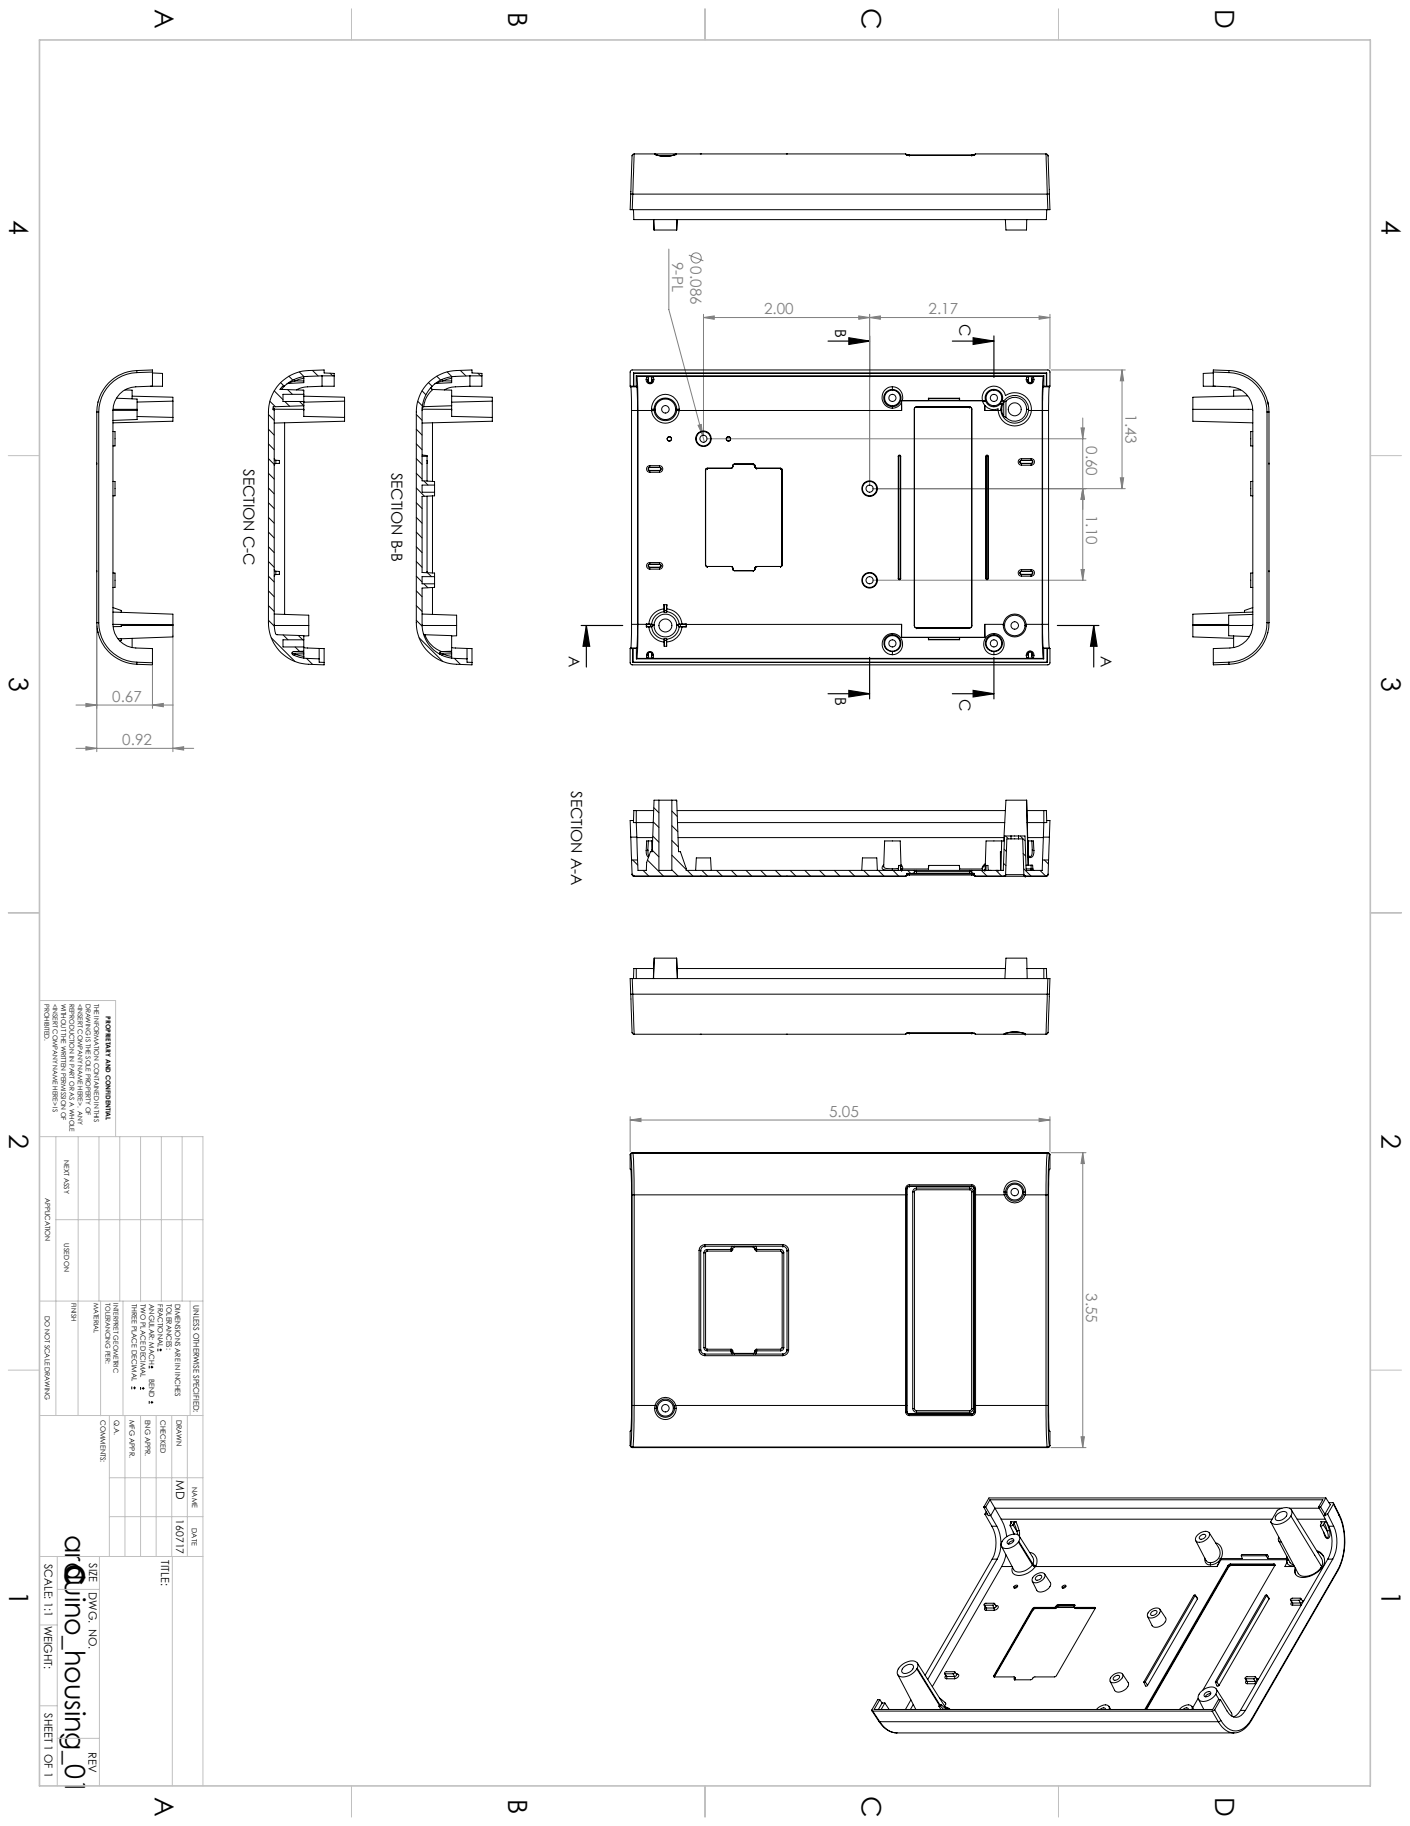
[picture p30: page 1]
SECTION A-A; SECTION C-C; SECTION B-B; arduino_housing_01; SHEET 1 OF 1; SCALE: 1:1 WEIGHT:; SIZE; TITLE:; NAME DATE; COMMENTS:; MFG APPR.; ENG APPR.; CHECKED; DRAWN; FINISH; MATERIAL; TOLERANCING PER:; INTERPRET GEOMETRIC; ANGULAR: MACH; FRACTIONAL; TOLERANCES:; BEND; APPLICATION; PROHIBITED.

<INSERT COMPANY NAME HERE> IS

WITHOUT THE WRITTEN PERMISSION OF

REPRODUCTION IN PART OR AS A WHOLE

<INSERT COMPANY NAME HERE>. ANY

DRAWING IS THE SOLE PROPERTY OF

THE INFORMATION CONTAINED IN THIS

PROPRIETARY AND CONFIDENTIAL

USED ON NEXT ASSY

THREE PLACE DECIMAL

TWO PLACE DECIMAL

DIMENSIONS ARE IN INCHES

UNLESS OTHERWISE SPECIFIED:

DO NOT SCALE DRAWING

REV DWG. NO.

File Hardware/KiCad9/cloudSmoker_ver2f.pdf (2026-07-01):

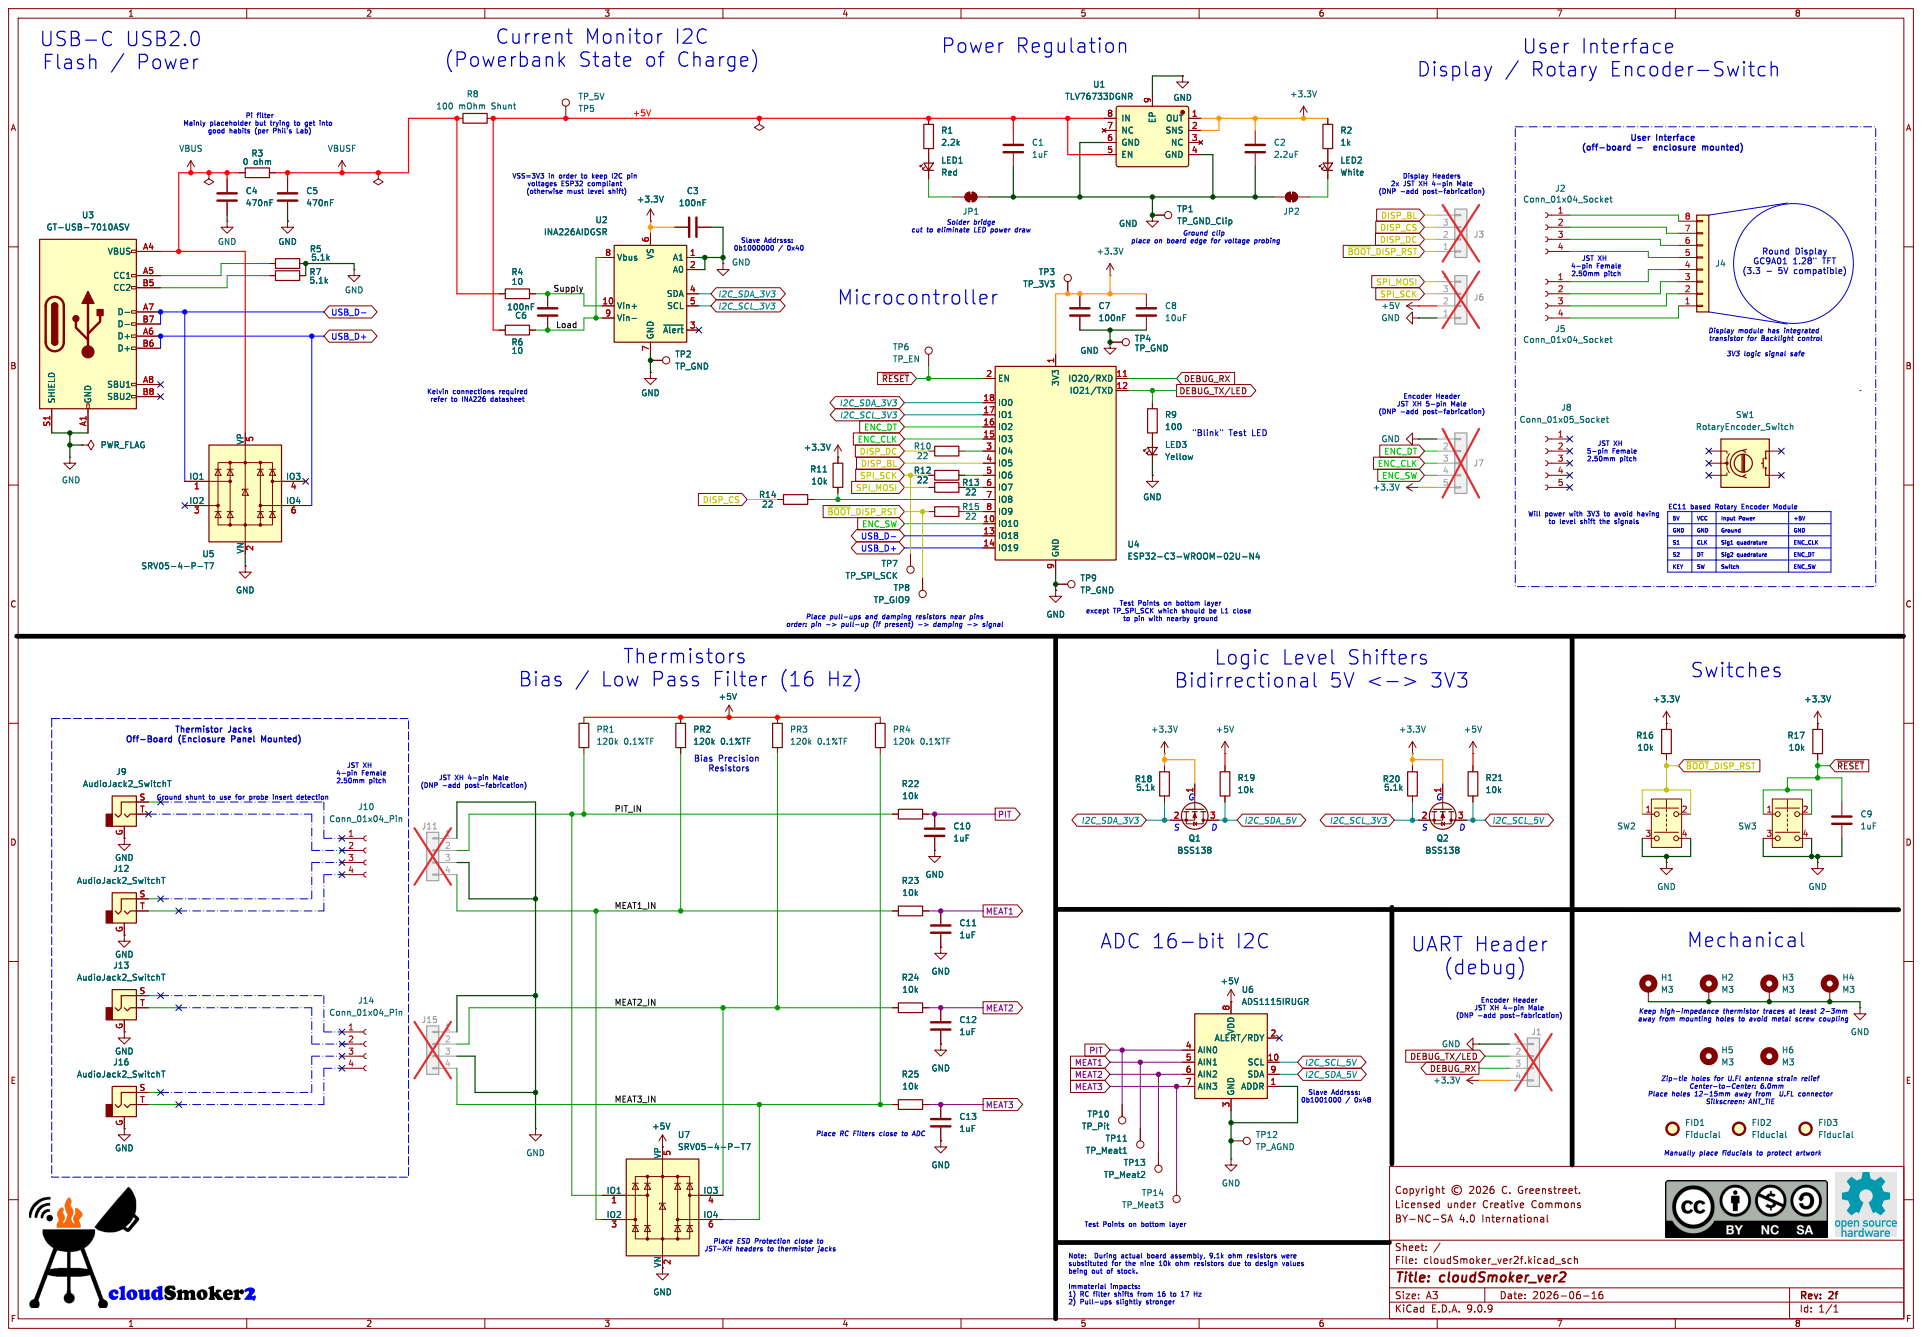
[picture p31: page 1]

Current Monitor I2C
(Powerbank State of Charge)

Display / Rotary Encoder-Switch

9 OUT 1 SNS 2 NC 3 GND 4 U1 TLV76733DGNR

9 OUT 1 SNS 2 NC 3 GND 4

good habits (per Phil's Lab)

VSS=3V3 in order to keep I2C pin

7 A1 1 A0 2 SDA 4 SCL 5 ~{Alert}3 U3 GT-USB-7010ASV SHIELD S1 GND A1 VBUS A4 CC1 A5 CC2 B5 D- A7 D- B7 D+ A6 D+ B6 SBU1 A8 SBU2 B8 PWR_FLAG

EC11 based Rotary Encoder Module R6

to level shift the signals

Test Points on bottom layer except TP_SPI_SCK which should be L1 close

Bias / Low Pass Filter (16 Hz)

3 ALERT/RDY 2 SCL 10 SDA 9 ADDR 1 +5V R21

3 ALERT/RDY 2 SCL 10 SDA 9 ADDR 1 U6ADS1115IRUGR

Place RC Filters close to ADC

Test Points on bottom layer

substituted for the nine 10k ohm resistors due to design values being out of stock.

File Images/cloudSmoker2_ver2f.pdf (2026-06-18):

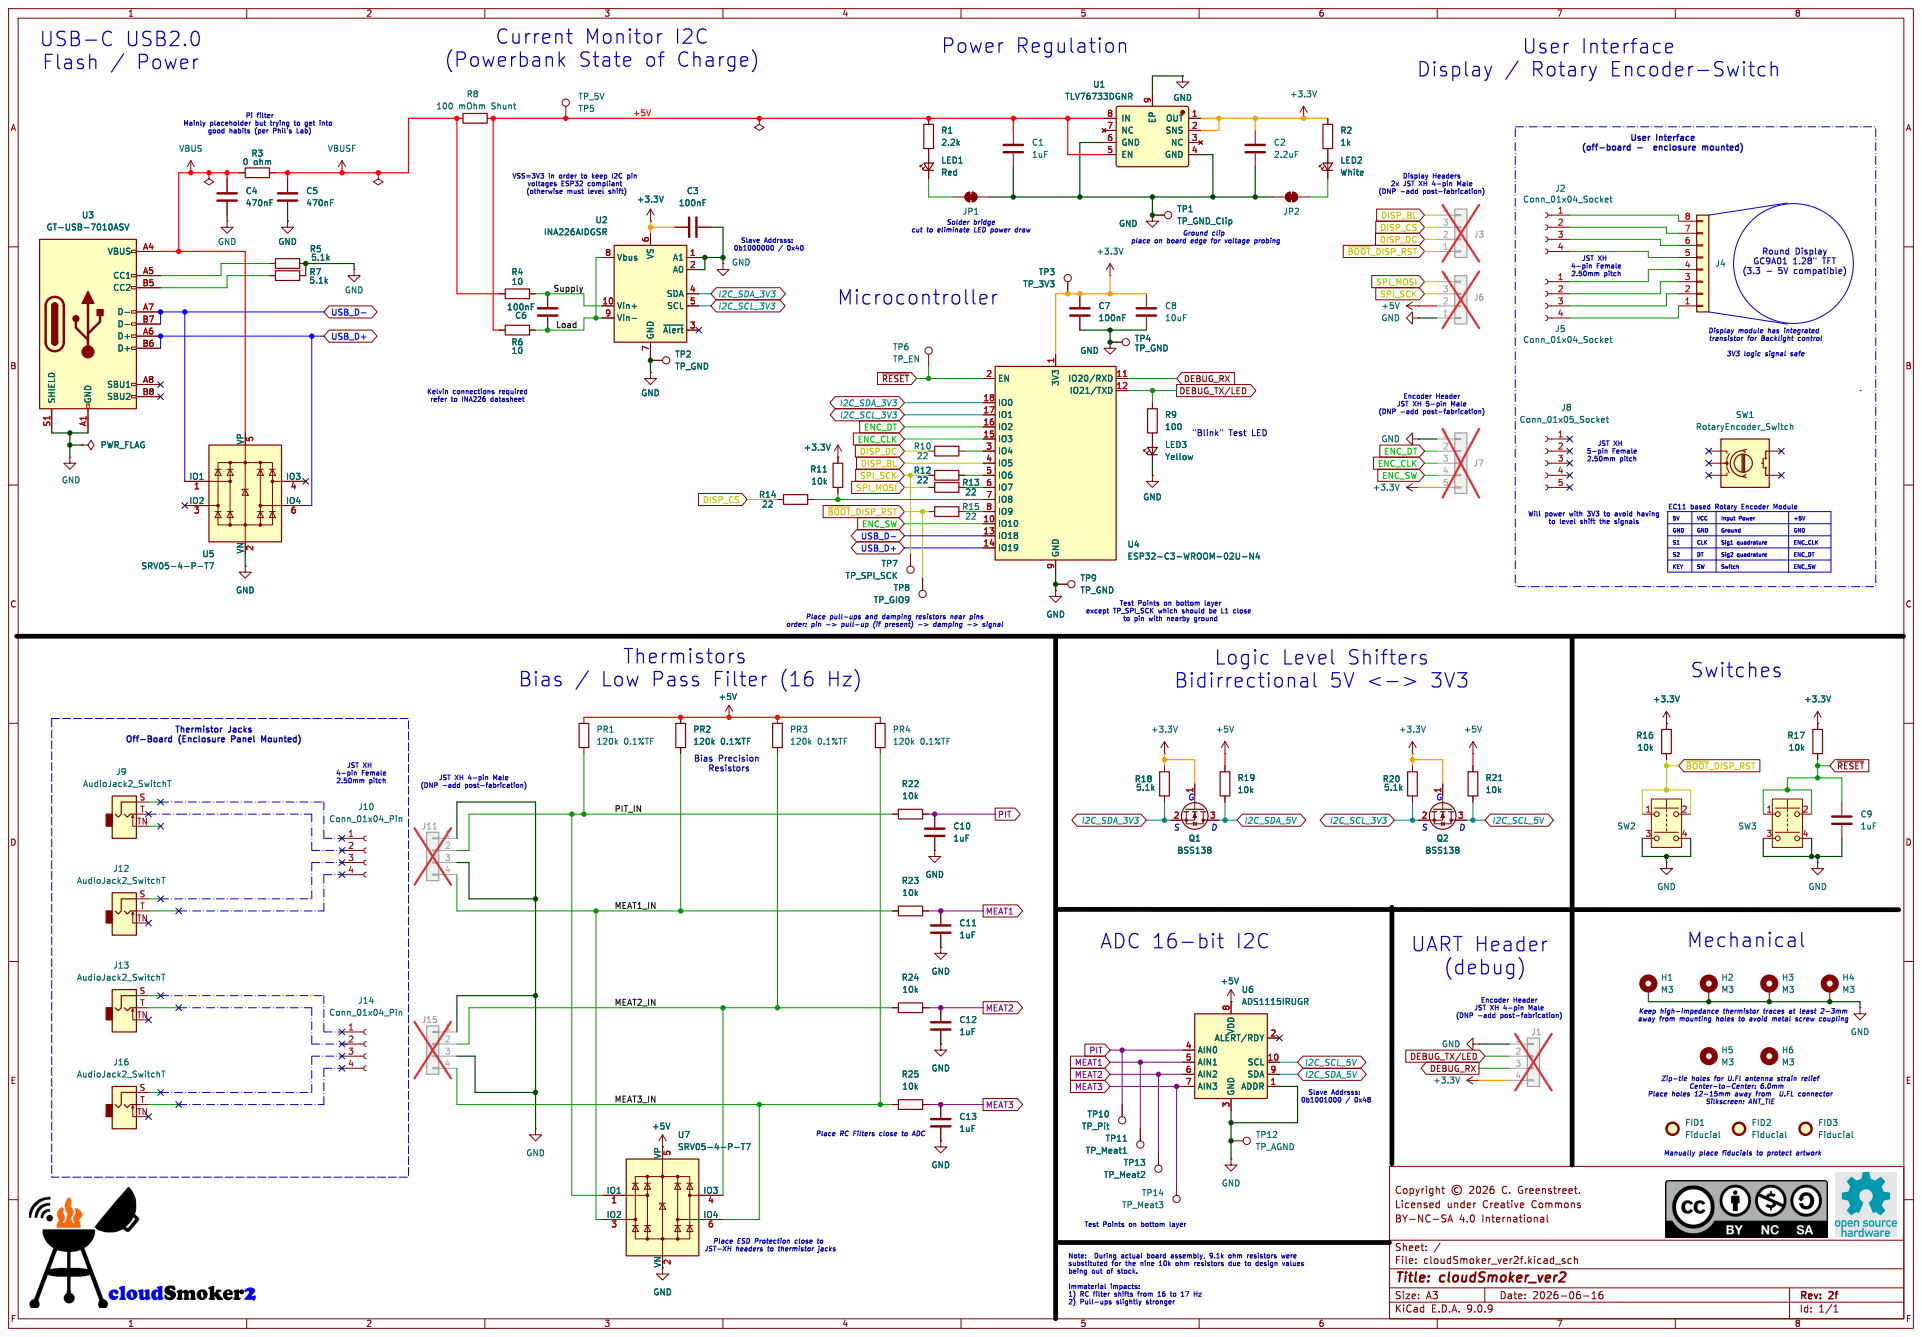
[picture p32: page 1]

(Powerbank State of Charge)

Display / Rotary Encoder-Switch

9 OUT 1 SNS 2 NC 3 GND 4 U1 TLV76733DGNR

9 OUT 1 SNS 2 NC 3 GND 4

place on board edge for voltage probing G

VSS=3V3 in order to keep I2C pin

7 A1 1 A0 2 SDA 4 SCL 5 ~{Alert}3 TP2 TP_GND GND

Display module has integrated

EC11 based Rotary Encoder Module

to level shift the signals

to pin with nearby ground

Bias / Low Pass Filter (16 Hz)

3 ALERT/RDY 2 SCL 10 SDA 9 ADDR 1 +5V GND GND

3 ALERT/RDY 2 SCL 10 SDA 9 ADDR 1 U6ADS1115IRUGR

Test Points on bottom layer

substituted for the nine 10k ohm resistors due to design values being out of stock.

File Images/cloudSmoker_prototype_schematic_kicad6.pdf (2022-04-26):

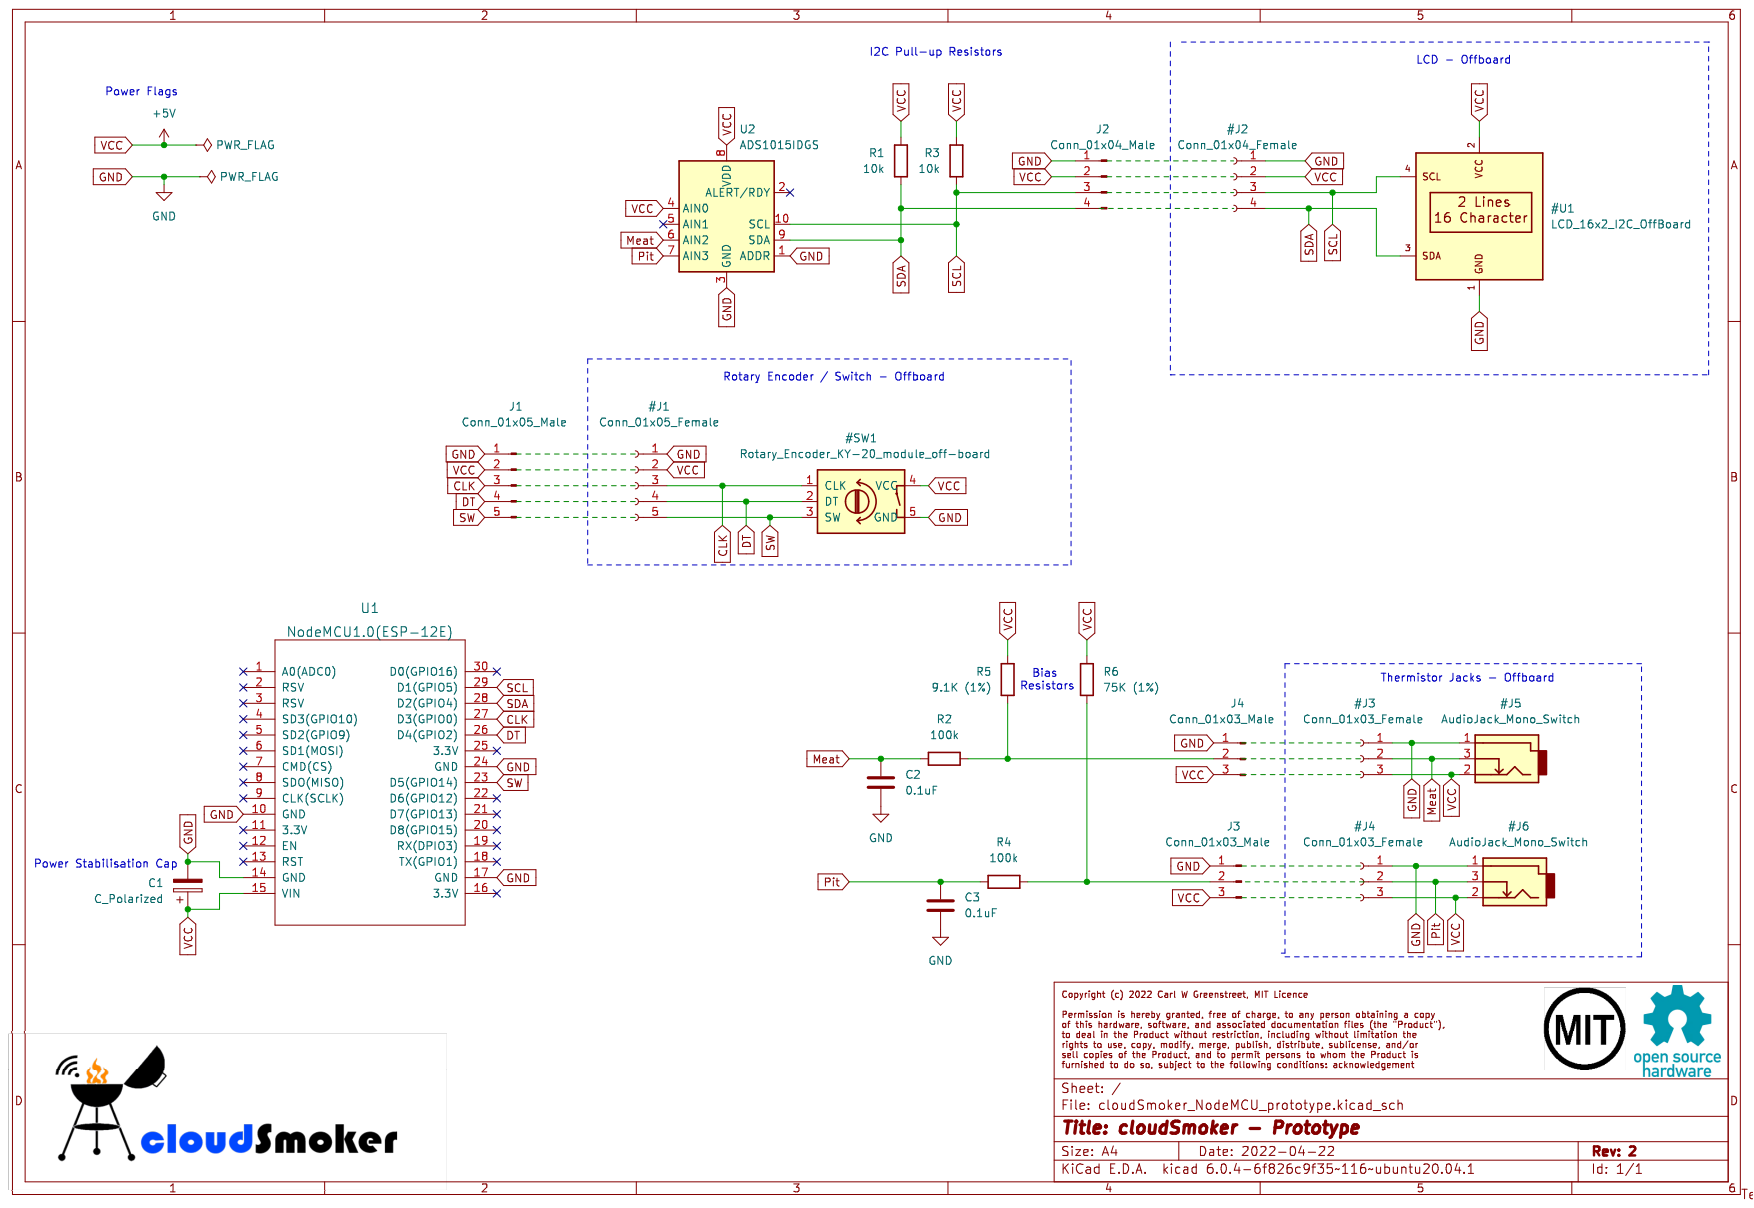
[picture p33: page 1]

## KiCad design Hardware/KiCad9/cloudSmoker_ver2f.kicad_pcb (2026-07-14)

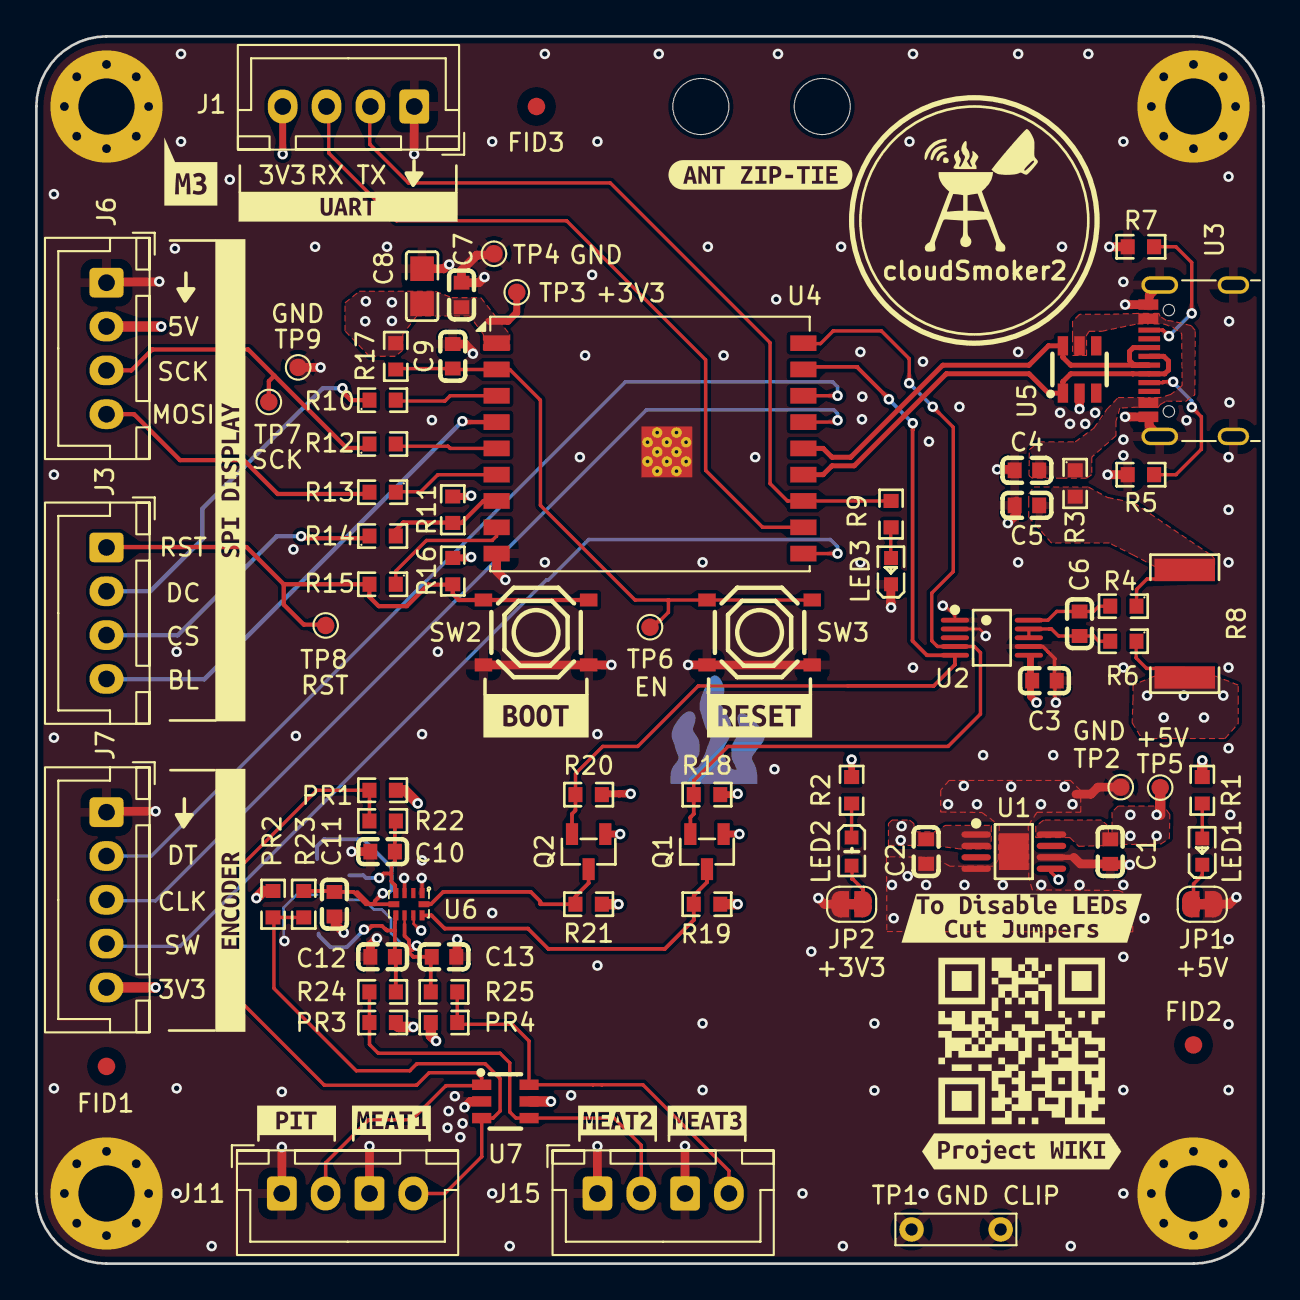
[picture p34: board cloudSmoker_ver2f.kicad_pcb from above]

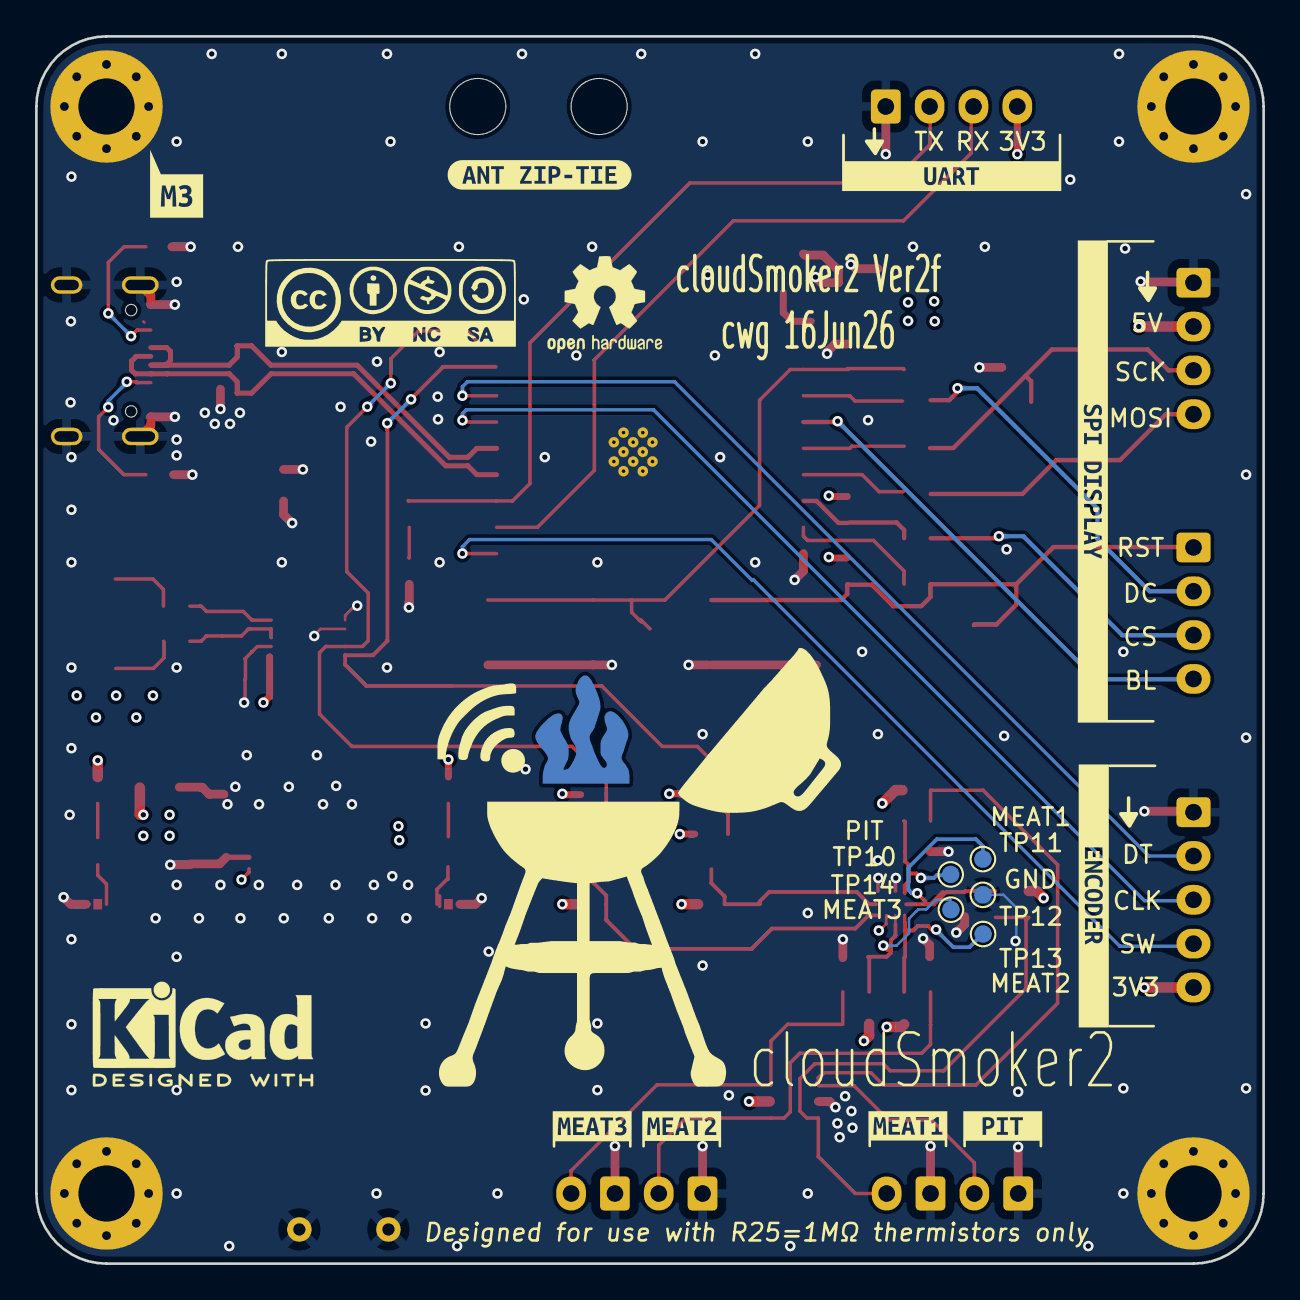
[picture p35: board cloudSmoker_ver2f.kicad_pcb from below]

Board: 4 copper layers, 70.0 x 70.0 mm, 110 parts (14 on the bottom side), 45 nets.

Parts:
C1, C9, C10, C11, C12, C13: 1uF; CL10A105KB8NNNC
C2: 2.2uF; CL10A225KO8NNNC
C3, C6, C7: 100nF; CC0603KRX7R9BB104
C4, C5: 470nF; CC0603KRX7R9BB104
C8: 10uF; CL21A106KAYNNNE
FID1, FID2, FID3: Fiducial; Fiducial_1mm_Mask2mm
H1, H2, H3, H4: M3; MountingHole_3.2mm_M3_Pad_Via
H5, H6: M3; MountingHole_3.2mm_M3
J1: Conn_01x02_Pin; JST_XH_B4B-XH-A_1x04_P2.50mm_Vertical
J3, J6: Conn_01x04_Pin; JST_XH_B4B-XH-A_1x04_P2.50mm_Vertical
J7: Conn_01x05; JST_XH_B5B-XH-A_1x05_P2.50mm_Vertical
J11, J15: Conn_01x04_Pin; JST_XH_B4B-XH-A_1x04_P2.50mm_Vertical_two_gnd
JP1, JP2: SolderJumper_2_Bridged; SolderJumper-2_P1.3mm_Bridged_RoundedPad1.0x1.5mm
LED1: Red; KT-0603R
LED2: White; 0603White_light_C2290
LED3: Yellow; FC-1608YXK-585F08
PR1, PR2, PR3, PR4: 120k 0.1%TF; PTFR0603B120KP9
Q1, Q2: BSS138; BSS138_C7420339
QR*****: QR-Code_cloudSmoker_Github_wiki
R1: 2.2k; 0603WAF2201T5E
R2: 1k; 0603WAF1001T5E
R3: 0 ohm; R0603_part-C21189_0-ohm
R4, R6: 10; R0603_part-C22859_10-ohm
R5, R7, R18, R20: 5.1k; 0603WAF5101T5E
R8: 100 mOhm Shunt; RLP25FEER100
R9: 100; 0603WAF1000T5E
R10, R12, R13, R14, R15: 22; R0603_part-C23345
R11, R16, R17, R19, R21, R22, R23, R24, R25: 10k; 0603WAF1002T5E
SW2, SW3: SW_Push_Dual; TS-1187A-B-A-B
TP1: TP_GND_Clip; TestPoint_Bridge_Pitch5.08mm_Drill0.7mm
TP2, TP4, TP9: TP_GND; TestPoint_Pad_D1.0mm
TP3: TP_3V3; TestPoint_Pad_D1.0mm
TP5: TP_5V; TestPoint_Pad_D1.0mm
TP6: TP_EN; TestPoint_Pad_D1.0mm
TP7: TP_SPI_SCK; TestPoint_Pad_D1.0mm
TP8: TP_GIO9; TestPoint_Pad_D1.0mm
TP10: TP_Pit; TestPoint_Pad_D1.0mm
TP11: TP_Meat1; TestPoint_Pad_D1.0mm
TP12: TP_AGND; TestPoint_Pad_D1.0mm
TP13: TP_Meat2; TestPoint_Pad_D1.0mm
TP14: TP_Meat3; TestPoint_Pad_D1.0mm
U1: TLV76733DGNR
U2: INA226AIDGSR
U3: GT-USB-7010ASV; USB_C_Receptacle_G-Switch_GT-USB-7010ASV clipped
U4: ESP32-C3-WROOM-02U-N4; ESP32-C3-WROOM-02U
U5, U7: SRV05-4-P-T7
U6: ADS1115IRUGR
kibuzzard-6A0E9251: G***; kibuzzard-6A0E9251
kibuzzard-6A0E9267: G***; kibuzzard-6A0E9267
kibuzzard-6A1EB0C4, kibuzzard-6A1EB0C4#2: G***; kibuzzard-6A1EB0C4
kibuzzard-6A28B67F, kibuzzard-6A28B67F#2: G***; kibuzzard-6A28B67F
kibuzzard-6A265CBA, kibuzzard-6A265CBA#2: G***; kibuzzard-6A265CBA
kibuzzard-6A265DB6, kibuzzard-6A265DB6#2: G***; kibuzzard-6A265DB6
kibuzzard-6A265E44, kibuzzard-6A265E44#2: G***; kibuzzard-6A265E44
kibuzzard-6A265EBE, kibuzzard-6A265EBE#2: G***; kibuzzard-6A265EBE
kibuzzard-6A266C13: G***; kibuzzard-6A266C13
kibuzzard-6A2660A1, kibuzzard-6A2660A1#2: G***; kibuzzard-6A2660A1
kibuzzard-6A262764, kibuzzard-6A262764#2: G***; kibuzzard-6A262764
kibuzzard-6A266895, kibuzzard-6A266895#2: G***; kibuzzard-6A266895
kibuzzard-6A276479: G***; kibuzzard-6A276479

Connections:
+3.3V: C2.1, C3.1, C7.1, C8.1, J1.4, J7.5, Q1.1 (G), Q2.1 (G), R2.1, R11.1, R16.2, R17.2, R18.2, R20.2, TP3.1, U1.1 (OUT), U1.2 (SNS), U2.6 (VS), U4.1 (3V3)
+5V: C1.1, J6.2, PR1.1, PR2.1, PR3.1, PR4.1, R1.1, R6.1, R8.2, R19.1, R21.1, TP5.1, U1.5 (EN), U1.8 (IN), U6.8 (VDD), U7.5 (VP)
/Load: C6.1, R6.2, U2.8 (Vbus), U2.9 (Vin-)
/MEAT1_IN: J11.4, PR2.2, R23.2, U7.3 (IO2)
/MEAT2_IN: J15.2, PR3.2, R24.2, U7.4 (IO3)
/MEAT3_IN: J15.4, PR4.2, R25.2, U7.6 (IO4)
/PIT_IN: J11.2, PR1.2, R22.2, U7.1 (IO1)
/Supply: C6.2, R4.2, U2.10 (Vin+)
DEBUG_RX: J1.3, U4.11 (IO20/RXD)
DEBUG_TX/LED: J1.2, R9.1, U4.12 (IO21/TXD)
DISP_BL: J3.4, U4.4 (IO5)
DISP_CS: J3.3, R14.1
DISP_DC: J3.2, R10.1
ENC_CLK: J7.3, U4.15 (IO3)
ENC_DT: J7.2, U4.16 (IO2)
ENC_SW: J7.4, U4.10 (IO10)
GND: C1.2, C2.2, C3.2, C4.2, C5.2, C7.2, C8.2, C9.2, C10.1, C11.1, C12.1, C13.1, H1.1, H2.1, H3.1, H4.1, J1.1, J6.1, J7.1, J11.1, J11.3, J15.1, J15.3, JP1.1 (A), JP2.2 (B), LED3.1 (K), R5.2, R7.2, SW2.3, SW2.4, SW3.3, SW3.4, TP1.1, TP2.1, TP4.1, TP9.1, TP12.1, U1.4 (GND), U1.6 (GND), U1.9 (EP), U2.1 (A1), U2.2 (A0), U2.7 (GND), U3.A1 (GND), U3.A12 (GND), U3.B1 (GND), U3.B12 (GND), U3.S1 (SHIELD), U4.9 (GND), U4.19 (GND), U5.2 (VN), U6.1 (ADDR), U6.3 (GND), U7.2 (VN)
I2C_SCL_3V3: Q2.2 (S), R20.1, U2.5 (SCL), U4.17 (IO1)
I2C_SCL_5V: Q2.3 (D), R21.2, U6.10 (SCL)
I2C_SDA_3V3: Q1.2 (S), R18.1, U2.4 (SDA), U4.18 (IO0)
I2C_SDA_5V: Q1.3 (D), R19.2, U6.9 (SDA)
MEAT1: C11.2, R23.1, TP11.1, U6.5 (AIN1)
MEAT2: C12.2, R24.1, TP13.1, U6.6 (AIN2)
MEAT3: C13.2, R25.1, TP14.1, U6.7 (AIN3)
unnamed: JP1.2 (B), LED1.1 (K)
unnamed: JP2.1 (A), LED2.1 (K)
unnamed: LED1.2 (A), R1.2
unnamed: LED2.2 (A), R2.2
unnamed: LED3.2 (A), R9.2
unnamed: R5.1, U3.A5 (CC1)
unnamed: R7.1, U3.B5 (CC2)
unnamed: R10.2, U4.3 (IO4)
unnamed: R12.2, U4.5 (IO6)
unnamed: R13.1, U4.6 (IO7)
unnamed: R11.2, R14.2, U4.7 (IO8)
unnamed: R15.1, U4.8 (IO9)
PIT: C10.2, R22.1, TP10.1, U6.4 (AIN0)
SPI_MOSI: J6.4, R13.2
SPI_SCK: J6.3, R12.1, TP7.1
USB_D+: U3.A6 (D+), U3.B6 (D+), U4.14 (IO19), U5.6 (IO4)
USB_D-: U3.A7 (D-), U3.B7 (D-), U4.13 (IO18), U5.1 (IO1)
VBUS: C4.1, R3.1, U3.A4 (VBUS), U3.A9 (VBUS), U3.B4 (VBUS), U3.B9 (VBUS), U5.5 (VP)
VBUSF: C5.1, R3.2, R4.1, R8.1
~BOOT_DISP_RST: J3.1, R15.2, R16.1, SW2.1, SW2.2, TP8.1
~RESET: C9.1, R17.1, SW3.1, SW3.2, TP6.1, U4.2 (EN)

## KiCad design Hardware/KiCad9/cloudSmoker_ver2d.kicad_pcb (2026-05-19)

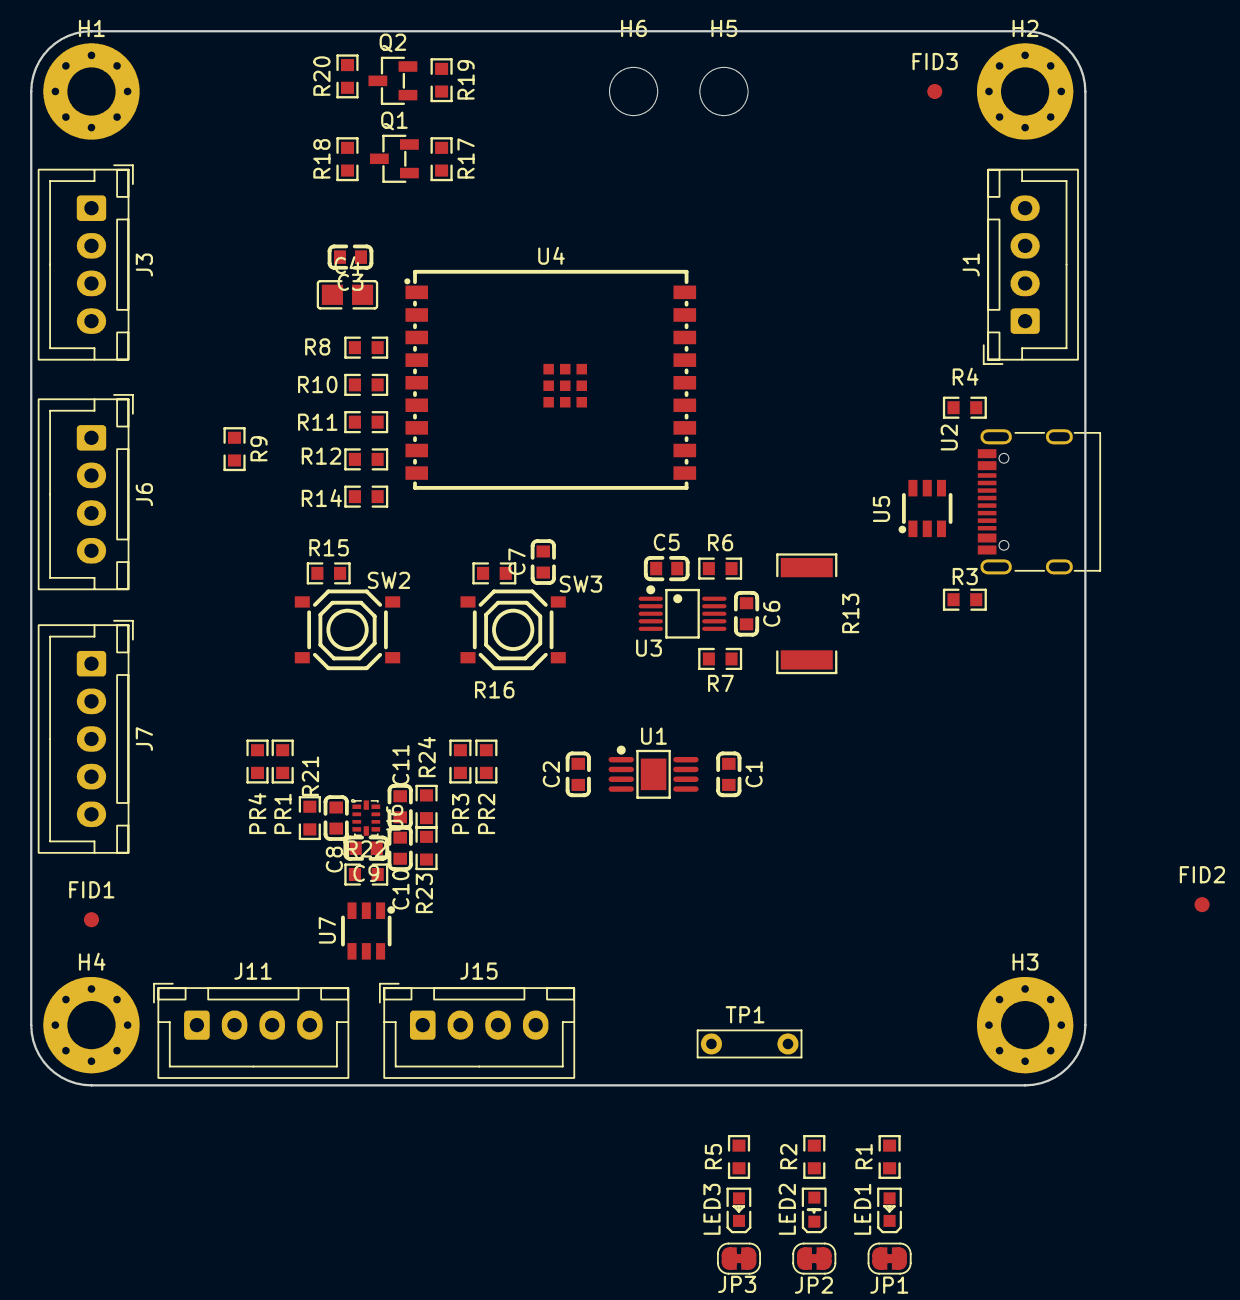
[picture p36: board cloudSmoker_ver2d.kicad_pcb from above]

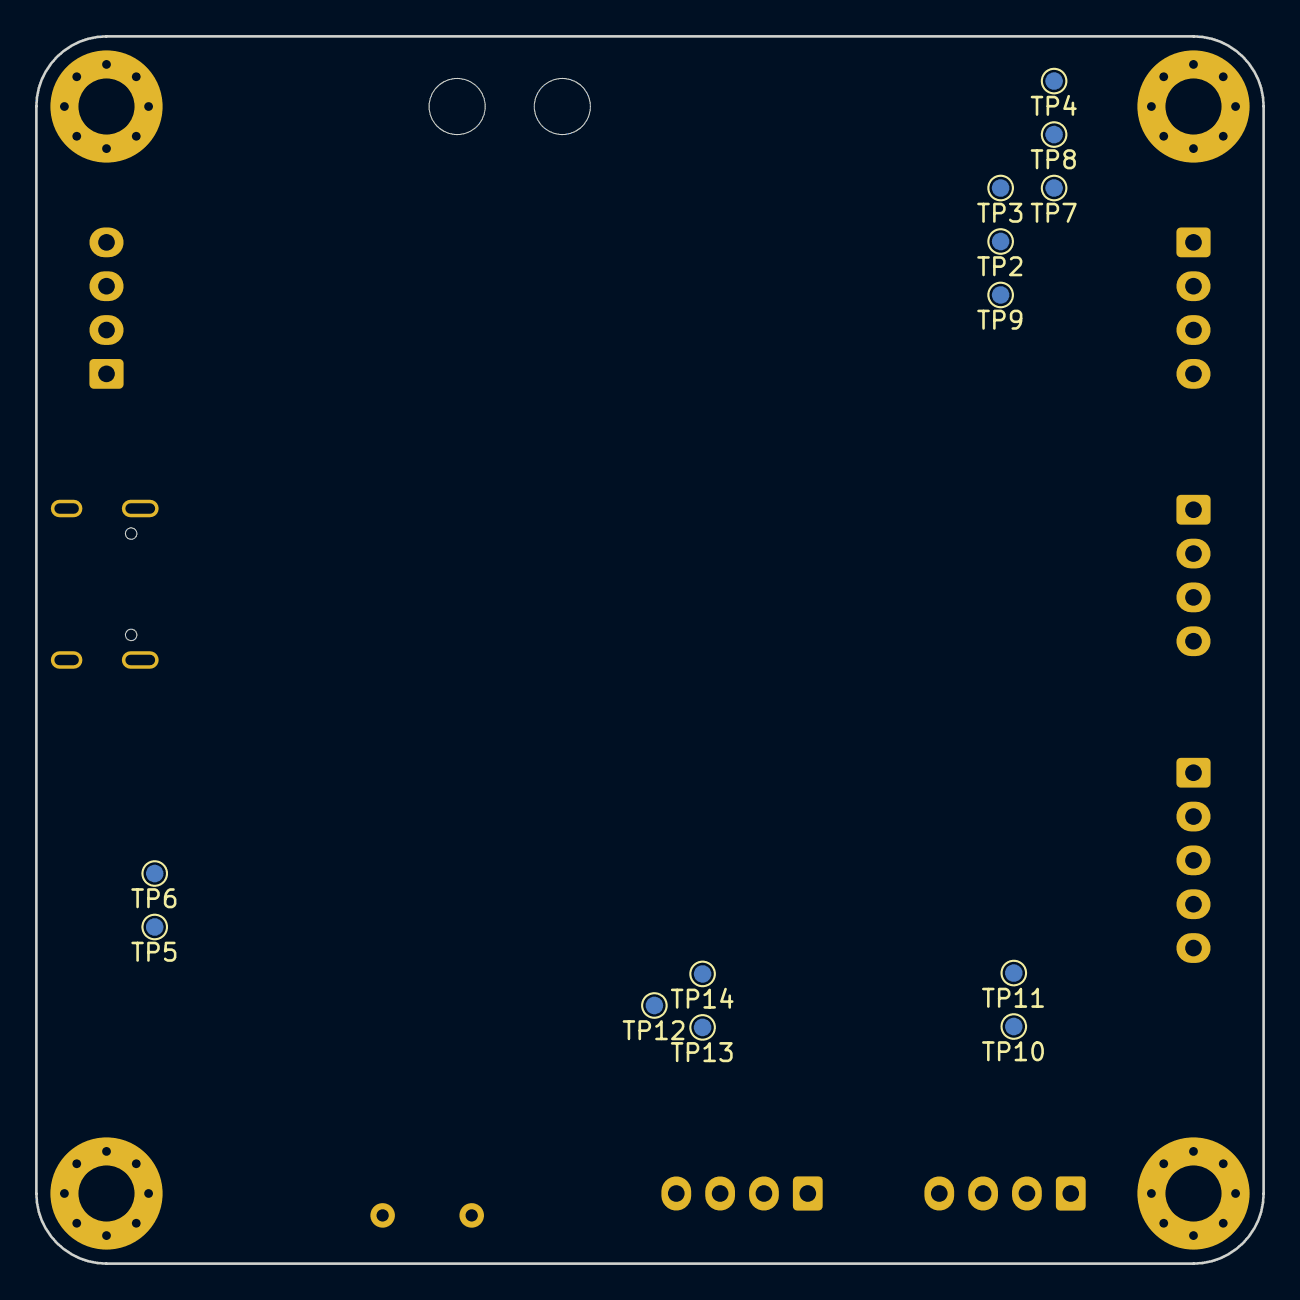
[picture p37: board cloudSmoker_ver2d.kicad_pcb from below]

Board: 4 copper layers, 70.0 x 70.0 mm, 85 parts (13 on the bottom side), 45 nets, no tracks yet.

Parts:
C1, C8, C9, C10, C11: 1uF; CL10A105KB8NNNC
C2: 2.2uF; CL10A225KO8NNNC
C3, C5, C6: 100nF; CC0603KRX7R9BB104
C4: 10uF; CL21A106KAYNNNE
C7: 1uF; CC0603KRX7R9BB104
FID1, FID2, FID3: Fiducial; Fiducial_1mm_Mask2mm
H1, H2, H3, H4: M3; MountingHole_3.2mm_M3_Pad_Via
H5, H6: M3; MountingHole_3.2mm_M3
J1: Conn_01x02_Pin; JST_XH_B4B-XH-A_1x04_P2.50mm_Vertical
J3, J6, J11, J15: Conn_01x04_Pin; JST_XH_B4B-XH-A_1x04_P2.50mm_Vertical
J7: Conn_01x05; JST_XH_B5B-XH-A_1x05_P2.50mm_Vertical
JP1, JP2, JP3: SolderJumper_2_Bridged; SolderJumper-2_P1.3mm_Bridged_RoundedPad1.0x1.5mm
LED1: Red; KT-0603R
LED2: White; 0603White_light_C2290
LED3: Yellow; FC-1608YXK-585F08
PR1, PR2, PR3, PR4: 120k 0.1%TF; PTFR0603B120KP9
Q1, Q2: BSS138; BSS138_C7420339
R1: 2.2k; 0603WAF2201T5E
R2: 1k; 0603WAF1001T5E
R3, R4, R17, R19: 5.1k; 0603WAF5101T5E
R5: 100; 0603WAF1000T5E
R6, R7: 10; PTFR0603B120KP9
R8, R10, R11, R12, R14: 22; PTFR0603B120KP9
R9, R15, R16, R18, R20, R21, R22, R23, R24: 10k; 0603WAF1002T5E
R13: 100 mOhm Shunt; RLP25FEER100
SW2, SW3: SW_Push_Dual; TS-1187A-B-A-B
TP1: TP_GND_Clip; TestPoint_Bridge_Pitch5.08mm_Drill0.7mm
TP2: TP_3V3; TestPoint_Pad_D1.0mm
TP3, TP6, TP9: TP_GND; TestPoint_Pad_D1.0mm
TP4: TP_EN; TestPoint_Pad_D1.0mm
TP5: TP_5V; TestPoint_Pad_D1.0mm
TP7: TP_SPI_SCK; TestPoint_Pad_D1.0mm
TP8: TP_GIO9; TestPoint_Pad_D1.0mm
TP10: TP_Pit; TestPoint_Pad_D1.0mm
TP11: TP_Meat1; TestPoint_Pad_D1.0mm
TP12: TP_AGND; TestPoint_Pad_D1.0mm
TP13: TP_Meat2; TestPoint_Pad_D1.0mm
TP14: TP_Meat3; TestPoint_Pad_D1.0mm
U1: TLV76733DGNR
U2: GT-USB-7010ASV; USB_C_Receptacle_G-Switch_GT-USB-7010ASV
U3: INA226AIDGSR
U4: ESP32-C3-WROOM-02U-N4
U5, U7: SRV05-4-P-T7
U6: ADS1115IRUGR

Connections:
+3.3V: C2.1, C3.1, C4.1, C5.1, J1.4, J7.5, Q1.1 (G), Q2.1 (G), R2.1, R9.1, R15.2, R16.2, R17.2, R19.2, TP2.1, U1.1 (OUT), U1.2 (SNS), U3.6 (VS), U4.1 (3V3)
+5V: C1.1, C6.2, J6.2, PR1.1, PR2.1, PR3.1, PR4.1, R1.1, R7.1, R13.2, R18.1, R20.1, TP5.1, U1.5 (EN), U1.8 (IN), U3.8 (Vbus), U5.5 (VP), U6.8 (VDD), U7.5 (VP)
/Load: R7.2, U3.9 (Vin-)
/MEAT1_IN: J11.4, PR2.2, R22.2, U7.3 (IO2)
/MEAT2_IN: J15.2, PR3.2, R23.2, U7.4 (IO3)
/MEAT3_IN: J15.4, PR4.2, R24.2, U7.6 (IO4)
/PIT_IN: J11.2, PR1.2, R21.2, U7.1 (IO1)
/Supply: R6.2, U3.10 (Vin+)
DEBUG_RX: J1.3, U4.11 (IO20/RXD)
DEBUG_TX/LED: J1.2, R5.1, U4.12 (IO21/TXD)
DISP_BL: J3.4, U4.4 (IO5)
DISP_CS: J3.3, R9.2, R12.1
DISP_DC: J3.2, R8.1
ENC_CLK: J7.2, U4.15 (IO3)
ENC_DT: J7.3, U4.16 (IO2)
ENC_SW: J7.4, U4.10 (IO10)
GND: C1.2, C2.2, C3.2, C4.2, C5.2, C7.2, C8.1, C9.1, C10.1, C11.1, H1.1, H2.1, H3.1, H4.1, J1.1, J6.1, J7.1, J11.1, J11.3, J15.1, J15.3, JP1.1 (A), JP2.2 (B), JP3.2 (B), R3.2, R4.2, SW2.3, SW2.4, SW3.3, SW3.4, TP1.1, TP3.1, TP6.1, TP9.1, TP12.1, U1.4 (GND), U1.6 (GND), U1.9 (EP), U2.A1 (GND), U2.A12 (GND), U2.B1 (GND), U2.B12 (GND), U2.S1 (SHIELD), U3.1 (A1), U3.2 (A0), U3.7 (GND), U4.9 (GND), U4.19 (GND), U5.2 (VN), U6.1 (ADDR), U6.3 (GND), U7.2 (VN)
I2C_SCL_3V3: Q2.2 (S), R19.1, U3.5 (SCL), U4.17 (IO1)
I2C_SCL_5V: Q2.3 (D), R20.2, U6.10 (SCL)
I2C_SDA_3V3: Q1.2 (S), R17.1, U3.4 (SDA), U4.18 (IO0)
I2C_SDA_5V: Q1.3 (D), R18.2, U6.9 (SDA)
MEAT1: C9.2, R22.1, TP11.1, U6.5 (AIN1)
MEAT2: C10.2, R23.1, TP13.1, U6.6 (AIN2)
MEAT3: C11.2, R24.1, TP14.1, U6.7 (AIN3)
unnamed: JP1.2 (B), LED1.1 (K)
unnamed: JP2.1 (A), LED2.1 (K)
unnamed: JP3.1 (A), LED3.1 (K)
unnamed: LED1.2 (A), R1.2
unnamed: LED2.2 (A), R2.2
unnamed: LED3.2 (A), R5.2
unnamed: R3.1, U2.A5 (CC1), U5.3 (IO2)
unnamed: R4.1, U2.B5 (CC2), U5.4 (IO3)
unnamed: R8.2, U4.3 (IO4)
unnamed: R10.2, U4.5 (IO6)
unnamed: R11.1, U4.6 (IO7)
unnamed: R12.2, U4.7 (IO8)
unnamed: R14.1, U4.8 (IO9)
PIT: C8.2, R21.1, TP10.1, U6.4 (AIN0)
SPI_MOSI: J6.4, R11.2
SPI_SCK: J6.3, R10.1, TP7.1
USB_D+: U2.A6 (D+), U2.B6 (D+), U4.14 (IO19), U5.6 (IO4)
USB_D-: U2.A7 (D-), U2.B7 (D-), U4.13 (IO18), U5.1 (IO1)
VBUS: C6.1, R6.1, R13.1, U2.A4 (VBUS), U2.A9 (VBUS), U2.B4 (VBUS), U2.B9 (VBUS)
~BOOT_DISP_RST: J3.1, R14.2, R15.1, SW2.1, SW2.2, TP8.1
~RESET: C7.1, R16.1, SW3.1, SW3.2, TP4.1, U4.2 (EN)

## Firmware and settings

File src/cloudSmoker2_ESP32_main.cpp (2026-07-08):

/* *************************************************************************************
 *   cloudSmoker2_ESP32_main
 *   V2.ESP32   (Ported from NodeMCU ESP8266 to Firebeetle ESP32 V4)
 *
 *  C W Greenstreet, cloudSmoker2, 1Jul26
 * Licence: GPLv3 (Licensed under the GNU GPLv3: Free to use and modify, but any public
 *   distribution must also share the full source code under this same license.
 *
 *   Purpose:  cloudSmoker Barbecue Temperature Monitor (Upgraded with 1.28" TFT Display)
 *               using breadboard as a programming test jig
 *
 *    Project Repository:  https://github.com/cwgstreet/cloudSmoker
 *    Project Wiki:        https://github.com/cwgstreet/cloudSmoker/wiki
 *
 *   Code intended to work with the following hardware:
 *   --------------------------------------------------------
 *   ESP32 (Firebeetle32 V4)
 *   1.28" GC9A01 Round TFT Display (via TFT_eSPI)
 *   EC11 Rotary Encoder Module with Push Button
 *   ADS1015 - 12 bit ADC; I2C addressable
 *   Maverick brand ET-723/733 (NPN thermistor) temperature probes; R25 = 10K ohm, Beta = 3950K
 *
 * ************************************************************************************
 */

// external libraries:
#include <ADS1X15.h>
#include <Arduino.h>  // PlatformIO IDE requirement
#include <Bounce2.h>
#include <NewEncoder.h>
#include <SPI.h>   // Master SPI bus management (Required for GC9A01 TFT)
#include <WiFi.h>  // UPGRADED: Replaced <ESP8266WiFi.h> for ESP32 compatibility
#include <WiFiManager.h>
#include <Wire.h>  // Master I2C bus management

// internal (user) libraries:
#include "cwg_ads1x15.h"  // ADS1x15 I2C ADC functionality
#include "cwg_steinhartHart.h"
#include "cwg_wifi.hpp"
#include "lcd.h"          // UPGRADED: with new TFT_eSPI adapter class framework
#include "myConstants.h"  // All pin mappings and constants
#include "peripherals.h"
#include "press_type.h"    // Wrapper library abstracting Yabl / Bounce2 routines
#include "smokerStates.h"  // cloudSmoker state machine functionality
#include "wrapEncoder.h"

// Always include ThingSpeak header file after other header files and custom macros
#include <ThingSpeak.h>

//! BEGIN DEBUG CODE BLOCK
#include <esp_system.h>

char bootResetReasonStr[24] = "";  // set once in setup(), shown on the splash screen for diagnosis

//? ************** Selective Debug Scaffolding *********************
// #define DEBUG_SERIAL 1
// #define DEBUG_LCD 1           // Configured for local TFT verification testing
// #define DEBUG_PRESSTYPE  1
// #define DEBUG_FREEMEM 1       // Configured for ESP32 internal Heap diagnostics
//?  end Selective Debug Scaffolding *********************************

//? *******************************************************************
//?   Global variables (Maintained as 2-Channel Stable for current phase)
//? *******************************************************************

// Temperature variables- global; all temps stored in degF and converted to DegC on the fly
float meatDoneTemp = 203;    // Default brisket target internal temp
float pitTempTarget = 225;   // Traditional low-and-slow cooking target temperature
float currentMeatTemp = 40;  // Initial baseline temperature
float currentPitTemp = 60;
bool degCFlag = 0;  // Temperature unit flag: 1 for Centigrade, 0 for Fahrenheit

// Analog telemetry globals
float voltageFactor = 0;
float batteryVoltage_v;
double voltagePit_medianFiltered_V;
double voltageMeat_medianFiltered_V;

// Timing metrics - global
long unsigned startCookTime_ms;
unsigned long previousMillis = 0;
unsigned long transmitInterval = 60000;  // Cloud data push rate
unsigned long previousDisplayMillis = 0;
unsigned long displayInterval = 15000;  // Time threshold for active status panel screens

// Operational flags
bool hasRunFlag = 0;
int16_t prevEncoderValue;

// Instantiate your global hardware instances explicitly
CWG_LCD lcd;

void setup() {
  Serial.begin(SERIAL_MONITOR_SPEED);

  esp_reset_reason_t resetReason = esp_reset_reason();
  switch (resetReason) {
    case ESP_RST_POWERON:
      strcpy(bootResetReasonStr, "RST:POWERON");
      break;
    case ESP_RST_EXT:
      strcpy(bootResetReasonStr, "RST:EXT_PIN");
      break;
    case ESP_RST_SW:
      strcpy(bootResetReasonStr, "RST:SW");
      break;
    case ESP_RST_PANIC:
      strcpy(bootResetReasonStr, "RST:PANIC");
      break;
    case ESP_RST_WDT:
      strcpy(bootResetReasonStr, "RST:WDT");
      break;
    case ESP_RST_BROWNOUT:
      strcpy(bootResetReasonStr, "RST:BROWNOUT");
      break;
    default:
      snprintf(bootResetReasonStr, sizeof(bootResetReasonStr), "RST:OTHER(%d)", resetReason);
      break;
  }
  Serial.print(F("Reset reason: "));
  Serial.println(bootResetReasonStr);

  delay(1000);
  Serial.println("\n--- cloudSmoker 2 System Booting (ESP32) ---");

  // debugging statements follow
  Serial.println("Calling lcd.begin()");  // debug
  lcd.begin();
  Serial.println("LCD Initialised");  // debug
  lcd.clearScreen();

  Serial.println("Before Encoder Init");
  encoder.initialise();
  Serial.println("After Encoder Init");  // If this message is not seen, it's hung in initialise()

  WifiManager_initialise();
  Serial.println("Skipped WiFi, entering loop setup");

  // Initialise button press context tracking
  button.begin(BUTTON_PIN);

  // Enter initial splash sequence handling
  smokerState = splashScreen;

  // Configure ADS1015 I2C ADC hardware interface lines
  const uint8_t GAIN_SETTING = 0;       // 2/3x gain, max scale voltage: ±6.144V
  const uint8_t MODE_SETTING = 1;       // Single shot operation
  const uint8_t DATA_RATE_SETTING = 4;  // Baseline sampling configuration
  ads1015.initialise(GAIN_SETTING, MODE_SETTING, DATA_RATE_SETTING);

  // Execution hooks for debug routines
#ifdef DEBUG_SERIAL
  SerialTerminal.functionTest();
#endif

#ifdef DEBUG_LCD
  // Optional: Call a primitive test string loop pattern if needed
  lcd.showSplashScreen(degCFlag, meatDoneTemp, pitTempTarget);
#endif

#ifdef DEBUG_PRESSTYPE
  button.functionTest();
#endif
}

void loop() {
  // Keep processor threads stable on underlying FreeRTOS environments
  yield();

  // Check hardware input triggers
  button.update();

  // Handle primary state machine transitions passing the updated display reference
  processState(lcd);

  // ***** debug - ESP32 Native Free Heap Memory Checking *****
#ifdef DEBUG_FREEMEM
  static unsigned long lastMemCheck = 0;
  if (millis() - lastMemCheck > 5000) {
    lastMemCheck = millis();
    // UPGRADED: Replaced old AVR <MemoryFree.h> call with native ESP32 Heap APIs
    Serial.printf("[SYSTEM MEMORY] Free Heap: %d Bytes\n", ESP.getFreeHeap());
  }
#endif
}

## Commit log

2021-10-02 transfer files from cloudSmoker_old
    [CloudSmoker-2020-12-28-17-29-20.sch, CloudSmoker.kicad_pcb, CloudSmoker.sch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]
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2022-01-06 fix smokerState encoder value bug
2022-01-07 top level of showSettingsMenu() completed
    [results.csv]
2022-01-08 code temperature message string routines
    [results.csv]
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2022-01-16 fixed switch case statements
2022-01-18 improve menu
    [results.csv]
2022-01-20 fix settings menu temperature unit display bug
2022-01-20 work on settings - change temp targets WIP
    [diff.csv, diff.txt, results.csv]
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2022-02-19 code cwg_ads1x15 lib
    [diff.csv, diff.txt, results.csv]
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2022-03-09 debug and fix memory leak in medianFilterLib2
    [diff.csv, diff.txt, results.csv]
2022-03-10 restructure folders (dump old files)
    [diff.csv, diff.txt, results.csv]
2022-03-10 remove files now on .gitignore
    [Maverick ET-732 - 733 datasheet info.xlsx, diff.csv, diff.txt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]
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2022-04-26 update prototype schematic
    [cloudSmoker_NodeMCU_prototype.kicad_pcb, cloudSmoker_NodeMCU_prototype.kicad_sch]
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2022-04-26 update schematic
    [cloudSmoker_NodeMCU_prototype.kicad_sch]
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2026-04-27 update kicad cloudSmoker_ver2 files
    [CloudSmoker-2020-12-28-17-29-20.sch, CloudSmoker.kicad_pcb, CloudSmoker.sch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]
2026-04-27 kicad updates
    [cloudSmoker_ver2b.kicad_sch]
2026-04-28 kicad schematic updates
    [cloudSmoker_ver2b.kicad_sch]
2026-05-01 cloudSmoker schematic ver2b changes
    [cloudSmoker_ver2b.kicad_sch]
2026-05-06 update schematic le: Hardware/KiCad9/JLCImport.3dshapes/RLP25FEER100.step
    [cloudSmoker_ver2b.kicad_sch]
2026-05-06 remove "depreciated" files (usually old working versions)
    [cloudSmoker_ver2a.kicad_pcb, cloudSmoker_ver2a.kicad_pro.kicad_pcb, cloudSmoker_ver2a.kicad_pro.kicad_sch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]
2026-05-06 remove depreciated files from git tracking
    [cloudSmoker_ver2a.kicad_pcb, cloudSmoker_ver2a.kicad_pro.kicad_pcb, cloudSmoker_ver2a.kicad_pro.kicad_sch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]
2026-05-06 remove depreciated files
    [cloudSmoker_ver2a.kicad_pcb, cloudSmoker_ver2a.kicad_pro.kicad_pcb, cloudSmoker_ver2a.kicad_pro.kicad_sch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]
2026-05-06 create version 2c
    [cloudSmoker_ver2b.kicad_pcb, cloudSmoker_ver2b.kicad_sch]
2026-05-06 create ver2C and archive ver2B as deprecated
    [cloudSmoker_ver2c.kicad_pcb, cloudSmoker_ver2c.kicad_sch]
2026-05-19 update board files for v2d
    [cloudSmoker_v2-net_class_board_setup.csv, cloudSmoker_ver2c.kicad_pcb, cloudSmoker_ver2d.kicad_pcb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]
2026-05-22 update hardware files for version 2e
    [cloudSmoker_ver2e.kicad_pcb, cloudSmoker_ver2e.kicad_sch]
2026-05-24 update hardware version number to 2f
    [cloudSmoker_ver2f.kicad_pcb, cloudSmoker_ver2f.kicad_sch]
2026-06-01 Update cloudSmoker_ver2f
    [cloudSmoker_ver2f.kicad_pcb, cloudSmoker_ver2f.kicad_sch]
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2026-06-07 update hardware files for v2f
    [cloudSmoker_ver2f.kicad_pcb, cloudSmoker_ver2f.kicad_sch]
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2026-06-12 hardware updates
    [cloudSmoker_ver2f.kicad_pcb, cloudSmoker_ver2f.kicad_sch]
2026-06-14 update hardware files for cloudSmoker_ver2f
    [bom.csv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]
2026-06-18 updated: Hardware/KiCad9/cloudSmoker_ver2f.kicad_pcb
    [cloudSmoker_ver2f.kicad_pcb, cloudSmoker_ver2f.kicad_sch, positions.csv]
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2026-06-19 Fix typo in Thermistor section heading
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2026-06-30 update schematic audio jack symbol
    [cloudSmoker_ver2f.kicad_sch]
2026-06-30 fix platformio.ini pin assignments for encoder and display
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2026-07-08 updated gitigner, added enclosure files, added new images, added new step file for pcb
    [cloudSmoker2_enclosure_ver2a.FCStd, cloudSmoker_ver2f.kicad_pcb, cloudSmoker_ver2f.step]
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2026-07-14 Enclosure design updates, including new enclosure versions and updated models for components.
    [EC11_encoder_module.step, GC9A01_Dsiplay.step, Pulse_W1010_90_Folded.step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]
2026-07-22 update enclosure to ver2a (restart versioning as prev vers completely discarded)
    [Pulse_W1010_90_Folded.step, Pulse_W1010_Fully_Extended.step, Same_Sky_MJ1-2502.step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]
2026-07-24 enclosure construction updates (working on top)
    [cloudSmoker2_enclosure_ver2a.FCStd]
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2026-07-28 clean up depreciated models
    [cloudSmoker2_enclosure_ver2a-no-edge-finish.FCStd, temp.FCStd]
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2026-08-31 Update FreeCAD Enclosure file to version 2a-a (no chamfers / fillets)
    [cloudSmoker2_enclosure_ver2a-a.FCStd]
2026-09-06 freecad update, added multi-colour print files for top enclosure, renamed enclosure file to remove edge treatment
    [cloudSmoker2_enclosure_ver2a-a.FCStd, cloudSmoker2_enclosure_ver2a-no-edge-treatment.FCStd, cloudSmoker2_enclosure_ver2a.FCStd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]
2026-09-10 fixing enclosure errors - not done
    [cloudSmoker2_enclosure_ver2a.FCStd]
2026-09-13 iterate on model - 2nd prototype
    [cloudSmoker2_enclosure_ver2a-no-edge-treatment.FCStd, cloudSmoker2_enclosure_ver2b.FCStd, cloudSmoker2_ver2a_base_enclosure.step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]
2026-09-14 ver2 3D model completed
    [cloudSmoker2_enclosure_ver2b.FCStd, cloudSmoker2_ver2a_top_enclosure_display_clip.3mf, cloudSmoker2_ver2a_top_enclosure_multicolour.3mf]
2026-10-05 enclosure model updated to version 2b, with updated print files and renamed components to reflect the new version.
    [cloudSmoker2_enclosure_ver2b.FCStd, cloudSmoker2_ver2a_base_enclosure.step, cloudSmoker2_ver2b_base_enclosure.step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]
2026-10-06 update enclosure Ver2b print files and include snap-fit test files
    [cloudSmoker2_enclosure_ver2b.FCStd, cloudSmoker2_ver2b_base_enclosure.step, cloudSmoker2_ver2b_base_enclosure_v1.3mf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]
2026-10-06 print file corrections
    [cloudSmoker2_ver2b_base_enclosure_v1.3mf]
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2026-10-22 fixed schematic text note errors
2026-10-24 fix pin assignments for encoder and button in myConstants.h
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2026-10-24 fix monitor decoder for ESP32 exceptions/backtraces in platformio.ini
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2026-10-31 change partition layout to min_spiffs.csv to allow two application slots of about 1.875 MB each, with a 64 KB filesystem partition. This is needed for OTA updates to work correctly on the ESP32-C3.
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2026-10-31 add retry logic to alert sending for each probe, with a maximum number of attempts defined by NTFY_MAX_ATTEMPTS. fix ThingSpeak send function to include battery voltage once INA226 bus voltage is imp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
2026-11-06 fix min pit logic and make encoders wrap instead of hard limits branch main
2026-11-06 fix encoder direction globally. Clockwise increases numbers and moves through menus.
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2026-11-06 bug fixes on Power Bank settings entry
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2026-11-07 Power Bank swapping logic coded
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2026-11-09 BLE serial terminal, setup portal, and settings cleanup
    BLE serial (lib/bleserial):
    - Nordic UART service mirrors the USB serial log to a phone app
    - Phone commands run through the same command handler as USB
    - Output sent one piece at a time, with a status callback and timeout
    - Input collected into lines; a 300 ms quiet flush handles apps that
    send no newline
    - Pairing with a six-digit code shown on the BLE Serial settings
    screen, stored in NVS and generated on first use
    - Both characteristics require an encrypted link; bonds persist across
    reset
    - On/off setting in Settings, saved to NVS, default on
    Setup and settings (lib/devconfig, lib/cwg_wifi, lib/lcd):
    - Wi-Fi, ThingSpeak key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
2026-11-13 fix OTA device IP
2026-11-13 lcd: enlarge text buffers that were too small
    The BLE pair-code buffer was char code[16], so 'pair code 902818' (17 bytes with the terminator) was cut to 90281 on the settings screen. Pairing with the five-digit code fails: the device rejects the phone's confirm value (SMP confirm mismatch, enc_change status 1028) and no bond is stored. Pairing with the full six digits stores a bond, the bond survives a reset, and help replies.
    The bank line buffer was also 16 bytes. bankRemainingPct() clamps to 0-100, so the old size fitted in practice, but lcd.cpp cannot see the clamp and -Wformat-truncation warns. Both buffers are now 20 bytes.
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2026-11-14 pullupdate: add rollback guard and BLE status accessor
    The guard keeps an OTA image pending until it proves healthy. It confirms the image after two minutes if BLE is switched off or started, and rolls back otherwise. It overrides the framework's default, which accepts new images at startup. Tested by an OTA upload to cloudsmoker2: the image was confirmed. Rollback on a failing image is not yet tested.

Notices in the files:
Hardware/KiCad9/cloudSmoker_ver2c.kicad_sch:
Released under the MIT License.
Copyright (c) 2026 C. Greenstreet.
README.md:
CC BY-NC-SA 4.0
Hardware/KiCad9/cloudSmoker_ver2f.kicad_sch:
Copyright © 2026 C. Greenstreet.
